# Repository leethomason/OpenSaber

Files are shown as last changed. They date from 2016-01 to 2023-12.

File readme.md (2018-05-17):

**Welcome to Open Saber**

The goal of open saber is provide source code, circuit diagrams, and 
documentation for making an Arduino (and compatible) based lightsaber.
The focus is on the internals of the saber, not how to build the case.

Why? For the joy of the problem, working together, and learning / playing
with Arduinos. There are certainly commercial solutions to saber electronics,
but if you want to build and contribute to the code and internals, this site
is for you!

The information and documentation assume a basic knowledge of Arduinos,
electronics, soldering, etc.

In 2017, the design switch from through hole components, which have wires
and can be fairly easily hand soldered, to SMD components, which need
to be flow soldered in an oven. The current code uses only the SMD
approach. If you are interested in the through hole approach, check out
the source at FIXME

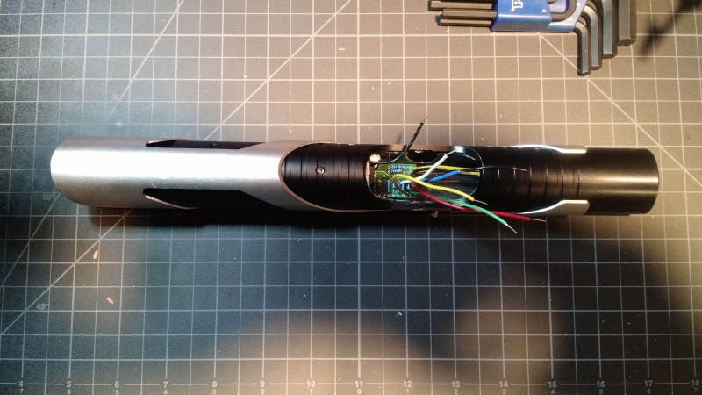
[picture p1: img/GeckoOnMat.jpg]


The Open Saber site / repo is 3 things:
- Overview of the (electrical) design of a saber.
- Source code for blade ignition, color, sound, etc. that runs on
  arduino class micro-controllers.
- Documentation & circuit diagrams for circuits and components.

An Open Saber electronics in action here: https://youtu.be/9_-Rfe4UBJM.

## Features:
- Support for 3 LED RGB "any color" saber 
- Flash on clash
- Motion and impact detection
- Sound font support
- Constant (average) current to LEDs
- Battery level tracking and indicator
- Command set to program saber with computer
- Recharge port / kill key port
- SPI support for secondary display, etc.
- Dotstar support for UI, etc.

## Status & Direction

There are over 5 working sabers on the OpenSaber design with cases
by SaberZ, UltraSabers, TCSS v1, and SaberForge ASP.

The version number - as much as it is consistent - references
the PCB board. The PCB board is called a "shield" because it sits on top
of a Teensy Microcontroller.

I use the largest possible SMD components to make it as straightforward
as possible for a human to solder. They are still *small*.

Generally speaking the shields sit on a Teensy 3.5. You can also use a
Teensy 3.2, but you need to connect an SD card on the SPI interface.
(The 3.2 does not have an integrated SD card.)

- Shield V3: Does *not* have integrated LED resistors. The emitter LED
  needs to have the correct resistors soldered in place.
- Shield V4: Has space for 3 through hole, small form factor, 1W 
  resistors. This can be much more tidy, but it's a longer board.

Note that many commits to the github repo are parts for a 3D
printer. While you are welcome to use them, the focus of 
this site is the electronics, which can be re-used from saber
to saber. The physical parts are unique to each saber (unless
you use a standard case, of course.)

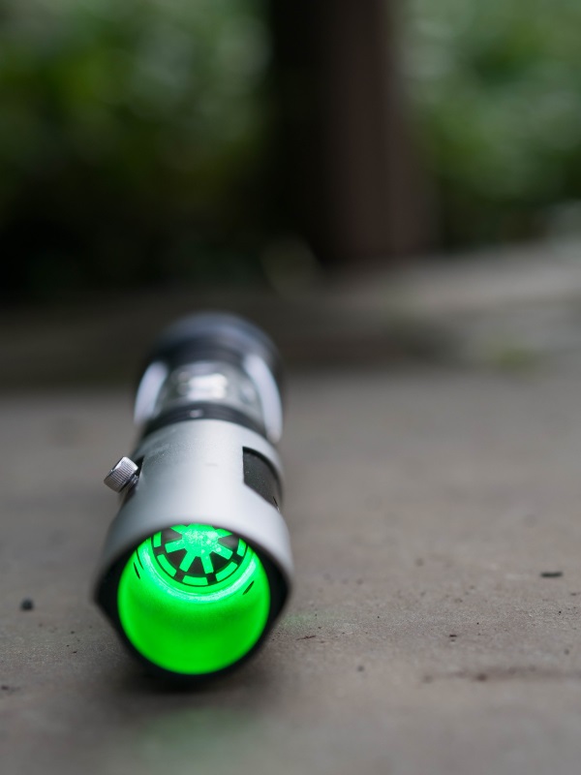
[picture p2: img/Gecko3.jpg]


## Alternate Approaches

- http://www.rocket-props.com/the-open-source-saber-project uses some 
  interesting ideas, including SMD componends and using buck-pucks.
  Nice approach, very different from this one.
- The Teensy Based Lightsaber http://fredrik.hubbe.net/lightsaber/
  has a similar electrical design, some innovative features, and
  doesn't use a PCB. (Which has pros and cons.)

## Resources

I am not affiliated with any of these, but have found them all useful.

### General
- The Custom Saber Shop at http://www.thecustomsabershop.com
  has all things saber. Often just abbreviated TCSS.

### How To
- Genesis Custom Sabers Shop Secrets: 
  https://www.youtube.com/playlist?list=PLBZx-DMVqx7druzwlBkXoZZhd30_0LXNS
  Lots of good info on wiring and techniques.
- "So you want to build a LED saber?" Different design than Open Saber,
  but still a nice overview: 
  http://forums.thecustomsabershop.com/showthread.php?2025-Step-2-I-have-decided-to-make-a-LED-saber

### Saber bodies
- The Custom Saber Shop (http://www.thecustomsabershop.com)
- UltraSabers http://www.ultrasabers.com/, in the "Build your own
  Lightsaber" section.

### LEDs
- LEDSupply. http://www.ledsupply.com/ has some nice RGB high power LEDs.

### Electronics
- Adafruit. I'm a huge Adafruit fan; great electronics and documentation.
  http://adafruit.com/
- PJRC who makes the Teensy and the Prop Shield.
  https://www.pjrc.com/
- Polulu makes some nice, simple breakout boards. https://www.pololu.com/
- Sparkfun. https://www.sparkfun.com/
- Mouser. http://www.mouser.com/ A huge selection of everything electronic.
- DigiKey. http://www.digikey.com/ A huge selection of everything electronic.
  I tend to have more success with DigiKey's search engine.
- Amazon has a surprisingly good selection of components.

## Architecture

An overview of the parts of a saber, with specific examples of the Gecko. 

Technically speaking, to organize you electrical thoughts, a saber is a *very* 
fancy flashlight. 

In roughly front to back order, an saber is:

1.  A **blade holder**. (1" is standard.)
2.  A **lens** to focus the LED. The lens is bought to match the LED,
    and narrower is usually better.
3.  3 **LEDs** in the 1-Watt each range. Red, green, blue, and 
    sometimes white or another color. I like both the Luxeon and Cree XPE-2.
    I haven't experimented with the 12W LEDs yet; electrically
    most of the designs should handle it, but the power from the battery
    and the cooling are potential issues.
4.  A **heat sink** for cooling the LED. Often part of the saber body. 
    TCSS provides them as well. LEDs are kept to 350ma - 400ma each (although 
    you can change this.) Many LED's, if cooled correctly, can take considerably
    more power. Conversly, many sabers with poor heat sinking fail over time
    as their LEDs burn out.
5.  **Power and Auxillary** switches (momentary on, typically 12mm). The
    code supports both a one button version and a two button version. Both
    versions support the same features except "clash sound" which is only
    supported in the 2 button version. If the switches have LED rings, the
    microcontroller will use them for power / volume display.
6.  **Electronics**. Please see the full discussion below.
7.  **Power port**. Typically 2.1 mm. If plugged into a Li-Ion charger,
    charges the battery (and disconnects the microcontroller). If a kill key
    is inserted, turns off the saber.
8.  **SD Card**. A simple SD card breakout board or integrated card. This is 
    where the sound fonts are stored. Note that the saber code WILL NOT work 
    without sound fonts stored and named properly on the MicroSD card. Also,
    if using the Teensy 3.5, the SD card is integrated.
9.  3.7v Li-Ion **battery**. TCSS and Adafruit both sell good, small,  long 
    lasting batteries. Need something rated 2000mAh or better. Amazon as well
    carries protected Li-Ion batteries. (The Panasonic NCR18650B 18650 has 
    been recommended.)
10. **Speaker**. TCSS and Adafruit carry them, as well as Mouser and Digikey. 
    (I've had a lot of inexpensive speakers arrived damaged from China, so I 
    do recommend a reputable supplier.)

## Directory Organization

- root
  - src - ardruino source code
    - saber - code for the saber itself
  - circuits
    - pcb - printed circurit board diagrams
  - img - images and diagrams used by the docs

## Wiring

FIXME new wiring diagram
  
### LEDs

LEDs are used in a bunch of places. Specific concerns are discussed
below, but for all the LEDs it's good to have a handly calculator.
The Vf comes from the LED data sheet. The Vsource depends on
which circuit it is connected to.

A LED calculator: http://led.linear1.org/1led.wiz

This calculator will select the next higher standard resistor,
which is almost always what you want. However, if you want to 
calculate the exact resistance:

R (ohms) = (Vs - Vf) / amps_through_led

Specific LED usage:

- The high power LED that lights the blade. Powered by the battery
  at 4.2 to 3.5 volts. Typcially about 1 Watt
  (or higher) per channel, and the resistors are typically 1 Watt.
  Typically a Vf of about 3.0 and expects 350mA of power. But
  get correct values from the datasheet! Generally has a resistor
  of 1-4 ohms. Note that once you select an LED, and add the
  resistor and specs into the `pins.h` file, the microcontroller
  will use PWM to keep the power at the specified level (or less.)
  This means you can sometimes round down on the resistor values:
  for example, if the `perfect` resistor is 1.6 ohms, and the 
  calculator recommends 1.8 ohms, you might use a 1.5ohm to give
  the microcontroller a little more "range" to work with.

- LED indicator lights, usually on the buttons. Powered at Vcc,
  3.3 volts, stable from the microcontroller. In theory these
  often take 20mA, about a 47 ohm resistors. But that is BRIGHT.
  I often use 470 or 1000 ohm resistors.

- DotStar smart LEDs. Used for user indicators. (Power meter,
  volume, etc.) Driven by the prop shield, requires no resistors.
  (The provided wiring diagram does not include this.)

### Power Bus

The saber uses a common ground. There are 4 positive power voltages. Please
be aware of the power supply. Shorts between the supplies can cause big
issues. It's very important to not "cross" the power supplies or use the 
wrong one. 

- Vbat, the battery power supply. Ranges from about 4.2 - 3.5V. Vbat delivers
  a **lot** of power, up to about 1A (1000mA) to the audio and LEDs. It also
  powers the micro-controllers.
- Vcc, a 3.3V, regulated, constant, low-amp supply. Powers the switch LEDs and 
  other indicators. Vcc is provided by the microcontroller.
- V5. If the propshield as well as Dotstar LEDs are being used, then there
  should be a 5 volt power supply. I often use a super-tiny booster 
  (from Polulu) to go from Vbat to V5 to power the microcontroller.
- USB. When the saber is plugged into USB, there is Yet Another power supply.
  WARNING: it is VERY easy to short a Teensy by plugging in a standard USB
  cable. This causes a short between the 5V USB power supply and the 3.7V
  Li-Ion battery. This will destroy the saber. Your options:
    - Cut the USB power on the Teensy board. I don't recommend this; it
      seems much too easy to "reconnect" via a short (metal dust?) or
      thermal expansion. I've burned out 3 microcrotrollers due to 
      mysterious issues when connecting USB.
    - Cut the power (red) line in the USB cable. Much more reliable...but
      you must *always* use the modified cable. I mark the USB port in 
      red paint and the cables with red tape.

#### Power Port
Convention, and the current design, uses a 2.1mm recharge jack. Wiring of the
jack is such that:
1. the battery charges when the charger is plugged in
2. the circuit is dead when there is a non-conductive kill key plugged in
3. the circuit is live when nothing is plugged in, which is also
   indicated by the ring LED if you use that type of momentary switch.

This is useful, and convention for almost all saber designs, but a little 
weird. For it to work (safely) for case #1, the grounded sleeve of the recharge 
port should be isolated from "true ground" and the case of the saber. You need 
to be careful with a metal port, or use an insulated plastic one.

#### 3V or 7V

Sabers run off 4 AAA, 3.7 Li-Ion, or 7.4 Li-Ion. OpenSaber is designed 
around a 3.7 Li-Ion.

Why?

3.7v
- Rechargable 
- Smaller than 7.4, competitive with AAA
- Efficient for resistors on LEDs. A typical LED forward voltage is 2-3 volts,
  so overall efficiency is about 80%.
- Buck/Boost converters make the 7.4 supply less interesting for the
  microcontroller and DotStars. 

Note that the actual battery voltage varies significantly, 
and the control circuit accounts for that.

### Electronics

The electronics are the heart of the OpenSaber project. The files are
ExpressPCB files. I regret the proprietary solution, but I've been happy
thusfar with the service.

The shield - which is the PCB that sits on top of the Teensy - collects 
together 1) an audio amplifier, 2) a DotStar LED controller,
3) an accelerometer, and 4) and emitter LED power onto one board. It also 
provides an SPI inteface connection for an external SD card, display, or 
similar.

- A **microcontroller**, the Teensy 3.2 or 3.5, is the micro-computer
  that runs the software. It controls the blade state, the color
  of the LEDs, the color of the blade, and does audio processing.

  It is soldered to a shield PCB. The microcontroller
  can be programmed directly via USB. The 3.5 includes an integrated
  SD card (handy!), but an SD breakout board can be connected via
  the SPI interface.

- **LED amplifier** The LED uses a 3 channel, 350ma (average) controller.
  The microcrontroller uses an amplifier bridge made of 3 MOSFETS
  to drive the LEDs. Voltage monitoring is used to keep the LED current
  constant. You may change the LED current in the software.

- **LED** a 1 WATT Cree or Luxeon LED in a star configuration is typical.
  The LED uses a common anode, as well as 3 control lines: Red, Green, and
  Blue. They 4 wires are connected from the LED to the front side of the 
  emitter electronics.

### Switches

The code assumes 1 or 2 switches.
- A: the main switch. Hold for power, tap for battery level indicator.
- B: the auxiliary switch. When the blade is on, tap for "blaster effect",
  hold for "lockup effect". When the blade is off, hold to toggle sound.
  When the sound turns on, hold for 1-4 flashes to set volume.

In a 2 switch configuration, you may also (when the blade is on) 
hold auxillary and then tap the main switch to cycle through the blade 
color / sound palettes.

In a 1 switch configuration, a tap mode switches between "blade", "palette",
and "volume". Long press either turns the blade on/off, or selects the 
palette or volume.

### Audio

Audio playback is integrated into the main micro controller. It takes
44.1kHz in; you will need to convert files to 44.1k. They are typically
*not* 44.1kHz when provided, so you will need to convert.
- http://www.foobar2000.org/
- http://www.huelix.com/audio-converter/

You can have up to 10 sound "fonts" or sound banks. Each font
needs to be in its own sub-directory, which will be the name of the font.

All the names can be postfixed with a number for random variation: `SWING` or
`SWING01` for example. Note that the card / code is limited to 8.3 filenames.
You can't mix names in a group; using both BLDON and POWERON in the same
sound font will confuse the sound output.

- "BLDON", "POWERON" blade ignition
- "BLDOFF", "POWEROFF" blade retraction
- "IDLE", "HUM" the background drone
- "IMPACT", "CLASH" is the sound of impacting another saber
- "MOTION", "SWING" is the basic saber motion sound
- "USRHOLD", "LOCKUP" is a user defined long sound, typically the sound 
  when 2 sabers are held together.
- "USRTAP", "BLASTER" is a user defined short sound, typically the sound
  of parrying blaster fire.

## Code

The code is really the heart of this project. The code
is set up to compile in the Arduino IDE, using the Teensyduino extension.

First you will need to set up libraries. Then you need to configure
you particular saber in "pins.h".

### Libraries

I feel guilty about every forked library; but it's hard to
work around API issues. Theser are minor forks, at least.

#### Accelerometer

The current design uses the (really great) LIS3DH.
https://github.com/leethomason/Adafruit_LIS3DH

#### OLED

The OLED display is required to compile, although it isn't supported
as part of OpenSaber yet. (I use it in a personal saber.)

https://github.com/leethomason/OLED_SSD1306

### Config Files

#### 'pins.h'

'pins.h' contains the wiring pinout, documentation, and features switches.
The tricky #define is the SERIAL_DEBUG macro. If on, you can connect
the USB header and debug the saber. However, without a USB connection, **the 
saber won't work if SERIAL_DEBUG = 1**. The serial port won't be found,
the timeouts kick in, and the saber essentially "locks up". It's a great to
be able to debug, but remember to SERIAL_DEBUG=0 and upload that sketch
when you are done.

Pins contains a bunch of other macros, which you can disable when you 
build the saber, and turn on one by one.

'pins.h' also contains the description of the LED: forward voltage, 
resistor values, etc. You need to set this for your particular build.

Note that there is an equation for UVOLT_MULT which controls the volt
meter. There's some variability; once the saber is assembled, I suggest
adjusting this value by checking computed vs. measured values. (Type 'vbat' on 
the command line to get the current computed value.)

##### "Constant Current" and tuning the voltmeter.

The OpenSaber code will maintain an average of 350mA current
(or whatever you specify) across the LED. This block of code in pins.h
is important for tuning:

````
  static const int32_t UVOLT_MULT = 6680;
  #define ID_STR "Gecko (Sentris Body) RGB Luxeon"

  static const int32_t RED_VF   = 2900;   // milli-volts
  static const int32_t RED_I    = 350;    // milli-amps
  static const int32_t RED_R    = 2400;   // milli-ohms
````

VF: forward voltage, from the LED spec.
I: milli-amps of power
R: the resistor value you used

And finally the UVOLT_MULT. It's a little tedious to calculate,
and doesn't turn out to be useful to do so. Once your saber 
is up and running, wait until it hits the 3.7 volt range.
Measure the power with a voltmeter. Run `vbat` on the saber
command line to get the measured value. Adjust UVOLT_MULT,
and recompile.

UVOLT_MULT' = UVOLT_MULT * V_measured / vbat

And then re-check the `vbat` just to be sure. It should 
be close, but doesn't need to be exact.

### Command line

If you connect via USB, you can open the COM port to the saber and
issue commands. Do this by opening the Serial Monitor and entering
comminds in the terminal that appears. This works irrespective of 
SERIAL_DEBUG.

The saber has 8 palettes. The palette is a combination of:
- blade color
- impact color
- sound font

- `bc` will return the current blade color for current palette. `bc #rrggbb`
  will set the blade color for the current palette. It will also show the 
  current draw of the color. I generally keep it at 1000mA or less, although
  you could theoretically draw about 1/2 the batter capacity. Do keep in mind
  how well your LED is able to sink heat.
- `ic` gets / sets the impact color or "blade flash".
- `pal` returns the current palette. `pal <0-7>` sets the current palette.
- `font` gets/sets the sound font in use.
- `fonts` lists the available sound fonts.
- `vol` and `vol <0-204>` gets and sets the current volume.
- `vbat' is the current battery level, in milli-volts. 4200 is fresh, 3700 is 
  nominal, 3500 is low. This is read from the Vmeter of the emitter circuit.
- `util` is the current utilization of each channel. It is computed from Vbat.
  `90 90 76` means that the saber will use 90% red, 90% green, and 76% of
  the blue channel. This keeps the average current through the LED constant.
  When Vbat drops to 3.7V, these will all be 100%.
- `pwm` is the current Pulse Width Modulation of the red, green, and blue LEDs.
- `mot` and `mot <1.1+>` gets and sets the threshold, in g-force, that
  the saber will detect as motion, and play the motion sound effects.
- `imp` and `imp <1.1+>` gets and sets the threshold, in g-force, that
  the saber will dectect as impact, and play the impact sound effects.
- `stat` will display all of the current saber settings.
- `reset` will reset the palettes to their default values.
- `accel` prints the current accelerometer output. Useful for checking
  calibration and that your axis are set up correctly.
- `test` runs the saber test suite.
- 'play' plays a sound on the SD card. You need the full name: 'play demichel.wav'
   or 'play bespin2/hum.wav'

## Future Direction

In practice I've found that there are two drivers to the design:
- Size. Smaller electronics leads to more features that can be packedd into
  theh saber. I try to balance size with ability to be soldered and
  wired up.
- Features for sabers. With every saber I build I put in some new or
  novel feature. (Although sometimes this is in the case, not electronics.)
  But those changes and improvements are reflected here

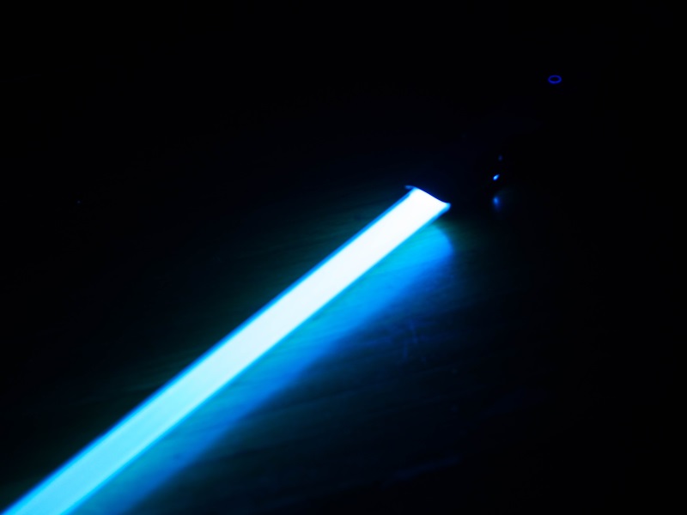
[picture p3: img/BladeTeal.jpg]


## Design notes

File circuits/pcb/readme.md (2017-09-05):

A collection of printed circuit boards used to make Open Saber designs.

`pcb` files are printed by ExpressPCB.

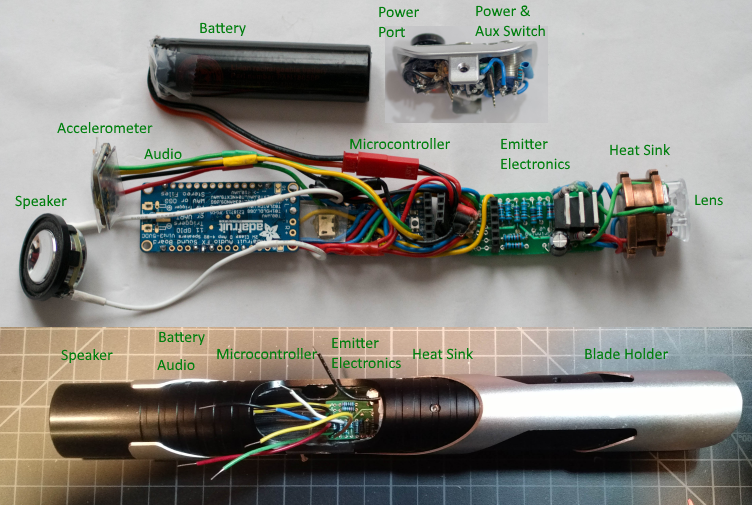
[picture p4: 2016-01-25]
img/Schematic.png

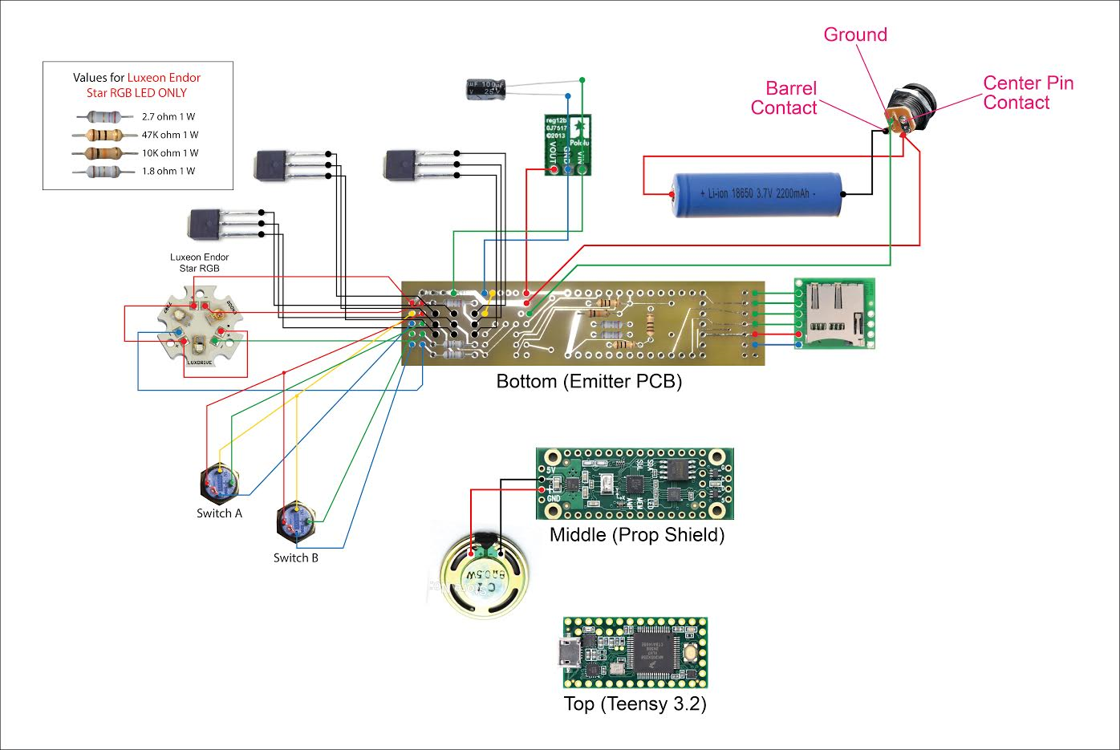
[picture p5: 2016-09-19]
img/v5prop.png

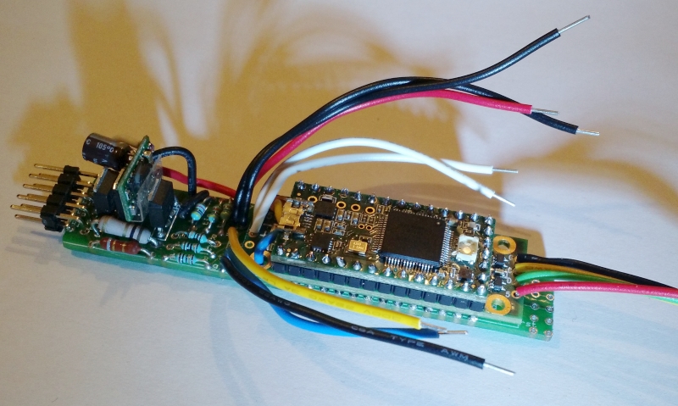
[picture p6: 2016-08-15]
img/v5propShield.jpg

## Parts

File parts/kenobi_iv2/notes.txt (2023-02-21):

* check mounting hardware works with 2mm mount
* set pin
* switch to rails to hold pcb

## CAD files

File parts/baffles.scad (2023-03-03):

use <shapes.scad>

D_OUTER = 2;
D_THIN  = 3;
D_INNER = 6;

module curveBridge(h, y, z, low, high)
{
    EPS = 0.1;

    // a + b*t + c*t*t + d*t*t*t
    al = low[0];
    bl = low[1];
    cl = low[2];
    dl = low[3];
    ah = high[0];
    bh = high[1];
    ch = high[2];
    dh = high[3];

    t = z;
    points = [
        [-EPS, al],
        [0.1, al + 0.1*bl + 0.1*0.1*cl + 0.1*0.1*0.1*dl],
        [0.2, al + 0.2*bl + 0.2*0.2*cl + 0.2*0.2*0.2*dl],
        [0.3, al + 0.3*bl + 0.3*0.3*cl + 0.3*0.3*0.3*dl],
        [0.4, al + 0.4*bl + 0.4*0.4*cl + 0.4*0.4*0.4*dl],
        [0.5, al + 0.5*bl + 0.5*0.5*cl + 0.5*0.5*0.5*dl],
        [0.6, al + 0.6*bl + 0.6*0.6*cl + 0.6*0.6*0.6*dl],
        [0.7, al + 0.7*bl + 0.7*0.7*cl + 0.7*0.7*0.7*dl],
        [0.8, al + 0.8*bl + 0.8*0.8*cl + 0.8*0.8*0.8*dl],
        [0.9, al + 0.9*bl + 0.9*0.9*cl + 0.9*0.9*0.9*dl],
        [1.0+EPS, al + 1.0*bl + 1.0*1.0*cl + 1.0*1.0*1.0*dl],
        [1.0+EPS, ah + 1.0*bh + 1.0*1.0*ch + 1.0*1.0*1.0*dh],
        [0.9, ah + 0.9*bh + 0.9*0.9*ch + 0.9*0.9*0.9*dh],
        [0.8, ah + 0.8*bh + 0.8*0.8*ch + 0.8*0.8*0.8*dh],
        [0.7, ah + 0.7*bh + 0.7*0.7*ch + 0.7*0.7*0.7*dh],
        [0.6, ah + 0.6*bh + 0.6*0.6*ch + 0.6*0.6*0.6*dh],
        [0.5, ah + 0.5*bh + 0.5*0.5*ch + 0.5*0.5*0.5*dh],
        [0.4, ah + 0.4*bh + 0.4*0.4*ch + 0.4*0.4*0.4*dh],
        [0.3, ah + 0.3*bh + 0.3*0.3*ch + 0.3*0.3*0.3*dh],
        [0.2, ah + 0.2*bh + 0.2*0.2*ch + 0.2*0.2*0.2*dh],
        [0.1, ah + 0.1*bh + 0.1*0.1*ch + 0.1*0.1*0.1*dh],
        [-EPS, ah]
    ];

    multmatrix(m = [ [0, 0, 1, 0],
                     [0, y, 0, 0],
                     [z, 0, 0, 0],
                     [0, 0, 0, 1]
                ])
    linear_extrude(height = h) {
        polygon(points=points);
    }  	
}

module bridge2(d, dz)
{
    SPACE_I = 6.0;
    SPACE_O = 1.0;

    difference() {
        intersection() 
        {
            tube(h=dz, do=d - SPACE_O, di=d - SPACE_I);
            union() {
                translate([-d, d*0.15, 0]) {
                    polygonYZ(d*2, [
                        [0,0], [dz*2, dz*2], [dz*3.5, dz*1.5], [dz*2.5, 0]
                    ]);
                }        
                translate([-d, -d*0.32, 0]) {
                    polygonYZ(d*2, [[0,0], [dz*2, dz*2], [dz*3, 0]]);
                }        
            }
        }
        BATTERY = 19.0; // padded
        translate([0, d/2 - BATTERY/2, 0])
            cylinder(h=d, d=BATTERY);
    }
}

module bridge4UpperWall(d, dz)
{
    intersection() 
    {
        cylinder(h=dz, d=d - 1.0);
        union() {
            translate([-d/2 - 1.0, d*0.08, 0]) {
                rotate([0, 0, -35]) {
                    polygonYZ(2.0, [
                        [0,0], 
                        [dz*3.0, dz*2], 
                        [dz*3.0, dz*1.5], 
                        [dz*3.0, 0]
                    ]);
                }
            }        
        }
    }
}

module bridge4(d, dz)
{
    intersection() 
    {
        tube(h=dz, do=d - D_OUTER, di=d - D_INNER);
        translate([-d, -d*0.32, 0]) {
            polygonYZ(d*2, [[0,0], [dz*2, dz*2], [dz*2, 0]]);
        }        
    }
    bridge4UpperWall(d, dz);
    mirror([-1, 0, 0]) bridge4UpperWall(d, dz);
}

module bridge5(d, dz)
{
    EPS = 0.1;
    D_BATTERY = 18.50 + 0.5;    // An 1850. Huh. 
    difference() {
        intersection() 
        {
            tube(h=dz, do=d - 2.0, di=d - 8.0);
            union() {
                translate([-d, -d*0.35, -EPS]) {
                    polygonYZ(d*2, [[0,0], [dz*2, dz*2], [dz*2, 0]]);
                }        
                translate([-d, 0, 0]) {
                    polygonYZ(d*2, [
                        [0,0], [dz, dz+EPS*2], 
                        [d*0.4, dz+EPS*2], [d*0.25, 0]
                    ]);
                }        
            }
        }
        translate([0, d/2 - D_BATTERY/2, 0])
            cylinder(d=D_BATTERY + 1.0, h = dz+EPS);
    }
}

module bridge3(d, dz)
{
    difference() {
        union() {
            intersection() 
            {
                tube(h=dz, do=d - D_OUTER, di=d - D_INNER);
                union() {
                    translate([-d, 0, 0]) {
                        curveBridge(d*2, dz, dz, 
                            [-2.5, 1.0, 1.0, 0.0], 
                            [-1.5, 0.5, 2.0, 0.0]);
                    }
                    translate([-d, 0, 0]) {
                        curveBridge(d*2, dz, dz, 
                            [ 0.0, 1.0, 1.0, 0.0], 
                            [ 1.5, 0.0, 1.5, 0.0]);
                    }
                }
            }
            color("silver") 
            intersection() 
            {
                tube(h=dz, do=d - D_THIN, di=d - D_INNER);
                translate([-d, 0, 0]) {
                    curveBridge(d*2, dz, dz, 
                        [ 2.5, -1.0, -1.5, 0.0], 
                        [ 3.0, -1.0, 0.5, 0.0]);
                }
            }
            color("silver")
            intersection() 
            {
                tube(h=dz, do=d - D_THIN, di=d - D_INNER);
                translate([-d, 0, 0]) {
                    curveBridge(d*2, dz, dz, 
                        [ -0.8, -1.0, -0.5, -0.2], 
                        [ -0.2, -1.0, -0.1, 0.0]);
                }
            }
        }
        BATTERY = 19.0; // padded
        translate([0, d/2 - BATTERY/2, 0])
            cylinder(h=d, d=BATTERY);
        X = 19.0; // padded
        translate([-X/2, -d/2, 0])
            cube(size=[X, d/2, dz]);
    }
}

translate([0, 0, 0]) tube(h=4, do=32, di=26);
translate([0, 0, 8]) tube(h=4, do=32, di=26);
translate([0, 0, 16]) tube(h=4, do=32, di=26);
translate([0, 0, 24]) tube(h=4, do=32, di=26);
translate([0, 0, 32]) tube(h=4, do=32, di=26);

translate([0, 0, 4]) bridge3(32, 4);
translate([0, 0, 12]) bridge3(32, 4);
translate([0, 0, 20]) bridge3(32, 4);
translate([0, 0, 28]) bridge3(32, 4);


/*
translate([0, 0, 0]) cube(size=[1, 30, 4]);
translate([0, 0, 8]) cube(size=[1, 30, 4]);
translate([-1, 4, 4]) 
    curveBridge(0.8, 4, 4, [0, 1.0, 0.3, 0.1], 
                           [1, 1.0, 0.3, 0.1]);
translate([-1, 16, 4]) 
    curveBridge(0.8, 4, 4, [0, 1.0, 0.3, 0.1], 
                           [1, 1.0, 0.3, 0.1]);                           

translate([0, 16, 4]) 
    curveBridge(0.8, 4, 4, [0, -1.0, 0.3, 0.1], 
                           [0.6, -1.0, 0.3, 0.1]);
*/

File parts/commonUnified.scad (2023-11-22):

use <shapes.scad>
use <baffles.scad>

Z_BATTERY_18650     = 65 + 4;
Z_BATTERY_18500     = 50 + 5;
D_BATTERY           = 18.50 + 0.5;    // An 1850. Huh. 

D_SWITCH            =  12.5;     // actually 12, by thread.
D_SWITCH_SUPPORT    =  16;
DY_SWITCH            =  -2;

D_PORT              =  7.9;
D_PORT_SUPPORT      =  12;
H_PORT              =  16;

INCHES_TO_MM        = 25.4;
X_MC                =   0.7 * INCHES_TO_MM;
Y_MC                =   9.0;
Z_MC                =   2.2 * INCHES_TO_MM + 0.1;
DY_MC               = -12.5;

X_CRYSTAL           =  11;
Y_CRYSTAL           =   8.5;
Z_CRYSTAL           =  30.0;

D_M2                = 1.7;

EPS = 0.01;
EPS2 = EPS * 2;

// Math ------------

function yAtX(x, r) = sqrt(r*r - x*x);

function isSmall(d) = d < 29.5;

// Utilities, shapes. ------------------------
module capsule(theta0, theta1, r=2, _mirror=false)
{
    hull() {
        rotate([-90, -0, theta0]) cylinder(h=20, r=r);
        rotate([-90, -0, theta1]) cylinder(h=20, r=r);
    }
    if (_mirror == true) hull() {
        rotate([-90, -0, 180 + theta0]) cylinder(h=20, r=r);
        rotate([-90, -0, 180 + theta1]) cylinder(h=20, r=r);
    }
}

module triCapsule(theta0, theta1, r=2, _mirror=false)
{
    theta0 = theta0 + 90;
    theta1 = theta1 + 90;

    hull() {
        rotate([0, 0, theta0]) 
            polygonYZ(100, [[0, -r], [-r, 0], [0, r]]);
        rotate([0, 0, theta1]) 
            polygonYZ(100, [[0, -r], [r, 0], [0, r]]);
    }
    if (_mirror == true) hull() {
        mirror([1,0,0]) rotate([0, -0, theta0]) 
            polygonYZ(100, [[0, -r], [-r, 0], [0, r]]);
        mirror([1,0,0]) rotate([0, -0, theta1]) 
            polygonYZ(100, [[0, -r], [r, 0], [0, r]]);
    }
}

module columnY(dx, dyFrom0, dz, diameter, baseDX=0, baseDZ=0)
{
    intersection() {
        translate([0, 0, -dz/2]) cylinder(h=dz, d=diameter);
        hull() {
            translate([-dx/2, -diameter/2, -dz/2]) {
                cube(size=[dx, diameter/2 + dyFrom0, dz]);
            }
            translate([-(dx + baseDX)/2, -diameter/2, -(dz + baseDZ)/2]) {
                cube(size=[dx + baseDX, 1, dz + baseDZ]);
            }
        }
    }
}

/*
    The green-sky version of the key joint was large, but
    secure. Problematic is that it clicked together on the y
    axis so it's hard to run the wires. The jJoint=true version
    is by far the more successful design.
*/
module keyJoint(dz, do, di, slot, angle=0)
{
    DZ = dz;
    YTRIM = slot ? 0.6 : 0.0;
    ZTRIM = slot ? 0.4 : 0.0;
    T = do - di;

    intersection() {
        if (slot) {
            tube(h=DZ+2, di=di, do=do+1);
        }
        else {
            OVERLAP = dz * 0.75;
            difference() {
                union() {
                    cylinder(h=dz-OVERLAP, d=do);
                    translate([0, 0, dz-OVERLAP]) cylinder(h=OVERLAP, d1=do, d2=do-(T*0.2));
                }
                translate([0, 0, -EPS]) cylinder(h=100, d=di);
            }
        }

        union() {
            rotate([0, 0, angle]) 
                tjoint(dz, do, di, YTRIM, ZTRIM, slot);
            mirror([-1, 0, 0 ]) rotate([0, 0, angle]) 
                tjoint(dz, do, di, YTRIM, ZTRIM, slot);
        }
    }
}

/* 
    A simple bridge at 45 degrees for
    unsupported printing. Made to hold
    switches, boards, etc. 
*/
module simpleBridge(diameter, dyToTop, yThickness, dz, addWidth=0, flatFill=false)
{
    L = 50;
    delta = yThickness * 1.2;

    // Writing this without the 'if' enclosing the PATH
    // declaration revealed all sorts of interesting
    // OpenScad bugs.
    //
    if (flatFill) {
        PATH = [
            [-L, dyToTop - yThickness - L],
            [0, dyToTop - yThickness],
            [L, dyToTop - yThickness - L],
            [L, dyToTop],
            [delta + addWidth, dyToTop],
            [-delta - addWidth, dyToTop],
            [-L, dyToTop]
        ];
        translate([0, 0, -dz/2]) {
            intersection() {
                cylinder(h=dz, d=diameter);
                polygonXY(dz, PATH);
            }
        }
    }
    else {
        PATH = [
            [-L, dyToTop - yThickness - L],
            [0, dyToTop - yThickness],
            [L, dyToTop - yThickness - L],
            [L, dyToTop - L],
            [delta + addWidth, dyToTop],
            [-delta - addWidth, dyToTop],
            [-L, dyToTop - L]
        ];
        translate([0, 0, -dz/2]) {
            intersection() {
                cylinder(h=dz, d=diameter);
                polygonXY(dz, PATH);
            }
        }
    }
}

module bridge(dx, dy, dz, inset=0)
{
    h1 = dx * 0.57;
    h2 = dx * 0.65; 
    pillar = dx * 0.20;
    
    PATH = [ 
        [-dx/2, dy], 
        [-dx/2 + h1, dy],
        [-dx/2, dy-h2]
    ];

    INSET = [
        [-dx/2 - EPS, dy - inset],
        [-dx/2 - EPS, dy + EPS],
        [-dx/2 + inset, dy + EPS]
    ];

    intersection() 
    {
        translate([-dx/2, 0, 0]) cube(size=[dx, dy, dz]);
        difference() {
            union() {
                polygonXY(dz, PATH);
                mirror([1,0,0]) polygonXY(dz, PATH);

                translate([-dx/2, 0, 0]) cube(size=[pillar, dy, dz]);
                mirror([1,0,0]) translate([-dx/2, 0, 0]) cube(size=[pillar, dy, dz]);
            }
            if (inset > 0) {
                translate([0, 0, -EPS]) {
                    polygonXY(dz + EPS2, INSET);
                    mirror([1,0,0]) polygonXY(dz + EPS2, INSET);
                }
            }
        }
    }
}

// Physical components. ----------------------

function zBattery(type) = (type == "18500") ? Z_BATTERY_18500 : Z_BATTERY_18650;

module battery(outer, type) {
    dz = zBattery(type);
    color("yellow") translate([0, outer/2 - D_BATTERY/2, 0]) {
        cylinder(d=D_BATTERY, h = dz + EPS2);
    }
}

function dynamicHeatSinkThread() = 20.2;  // 20.4 is loose (PHA), 20.1 tight (PLA)

module dynamicHeatSinkHolder(diameter)
{
    DZ = 10;
    D_HEAT_SINK_THREAD = dynamicHeatSinkThread();

    difference() {
        cylinder(h=DZ, d=diameter);
        translate([0, 0, -EPS]) 
            cylinder(
                h=DZ + EPS*2, 
                d1=D_HEAT_SINK_THREAD + 0.2, 
                d2=D_HEAT_SINK_THREAD + 0.4
            );
    }
}

module shortDynamicHeatSinkHolder(diameter)
{
    DZ = 4.0;
    D_HEAT_SINK_THREAD = dynamicHeatSinkThread();

    difference() {
        cylinder(h=DZ, d=diameter);
        cylinder(h=DZ + EPS, d=D_HEAT_SINK_THREAD);
    }
}


DOTSTAR_XZ = 5.6;
DOTSTAR_PITCH = 7;
DOTSTAR_STRIP_XZ = 12.4;

module dotstarLED(n, dy, pitch=DOTSTAR_PITCH)
{
    for(i=[0:n-1]) {
        translate([-DOTSTAR_XZ/2, 0, pitch * i - DOTSTAR_XZ/2]) {
            cube(size=[DOTSTAR_XZ, dy, DOTSTAR_XZ]);
        }
    }
}

function dotstarStripZLen(n, pitch=DOTSTAR_PITCH) = DOTSTAR_STRIP_XZ + pitch * (n-1);

module dotstarStrip(n, y0=0, y1=1, pitch=DOTSTAR_PITCH)
{
    translate([-DOTSTAR_STRIP_XZ/2, y0, -DOTSTAR_STRIP_XZ/2]) {
        cube(size=[ DOTSTAR_STRIP_XZ, 
                    y1 - y0,
                    dotstarStripZLen(n, pitch)]);
    }
}


module switch(outer, extend=false)
{
    D_OUTER_TOP = 13.8;
    D_INNER_TOP = 11.0;
    H_TOP       =  1.5;
    H_BODY      = 18;   // approx. connections below.

    color("yellow") {
        rotate([-90, 0, 0]) {
            translate([0, 0, outer/2 + DY_SWITCH]) {
                if (extend) {
                    cylinder(h=H_TOP+10, d=D_OUTER_TOP+1);
                }
                else {
                    cylinder(h=H_TOP, d1=D_OUTER_TOP+1, d2=D_INNER_TOP);
                }
                translate([0, 0, -H_BODY]) {
                    cylinder(h = H_BODY + EPS, d=D_SWITCH);
                }            
            }
        }
    }
}


module switchCounter()
{
    color("yellow") {
        rotate([90, 0, 0]) {
            cylinder(h=30, d=12);
        }
    }
}


module mc(widePart=0)
{
    color("aqua") {
        translate([-X_MC/2, 0, 0])
            cube(size=[X_MC, Y_MC, Z_MC]);
    
        Y_OFFSET = 4;
        if (widePart > 0) {
            translate([-widePart/2, Y_OFFSET, 0])
                cube(size=[widePart, Y_MC - Y_OFFSET, Z_MC]);
        }
    }
}

module crystal(dx=X_CRYSTAL, dy=Y_CRYSTAL, dz=Z_CRYSTAL)
{
    TAPER = 5;
    color("pink") scale([1.0, dy/dx, 1.0]) {
        cylinder(d=dx, h=dz - TAPER);
        translate([0, 0, dz - TAPER])
            cylinder(h=TAPER, d1 = dx, d2=dx *0.7);
    }
}

module port(extend=false)
{
    H = extend ? 30 : 21;
    rotate([-90, 0, 0]) {
        cylinder(h=H, d=D_PORT);
    }
}

module portCounter()
{
    H = 30;
    rotate([90, 0, 0]) {
        cylinder(h=H, d=12);
    }
}

module speakerStd28(bass)
{
    H_SPKR        =  3.5;
    D_SPKR        =  28;
    X_NOTCH       =  6;
    Z_NOTCH       =  6.0;

    color("yellow") {
        cylinder(h=H_SPKR, d=D_SPKR);
        translate([-X_NOTCH/2, 0, 0])
            cube(size=[X_NOTCH, D_SPKR * 0.6, Z_NOTCH]);
    }
}
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

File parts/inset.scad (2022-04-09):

use <shapes.scad>
use <commonUnified.scad>

SWITCH_BRIDGE_DZ = 5.8;
INNER_VIEW = false;

WOOD_DY = -8;
POWER_DY = 2.5;
EPS = 0.01;
EPS2 = EPS*2;

module attachPost(diameter, postDY, capsuleWidth)
{
    BRIDGE_DY = 5.5 + 3.4;
    BRIDGE_DZ = 10;

    BOLT_D = 4.5;
    NUT_W = 8.6;
    NUT_Y = 3.4;
    
    HOOK_X = 20;
    HOOK_Z = 2;

    INSET_DZ = 2;

    Y_TOP = diameter / 2 - postDY;

    intersection() {
        intersection() {
            translate([0, 0, -50]) cylinder(h=100, d=diameter);
            // This is a little limit to clean up the design.
            DELTA = 1.5;
            translate([-diameter/2 + DELTA, -100, -50])
                cube(size=[diameter - DELTA*2, 200, 200]);
        }
        union() {
            // bridge
            difference() {
                translate([-50, Y_TOP - BRIDGE_DY, -BRIDGE_DZ/2]) {
                    cube(size=[100, BRIDGE_DY, BRIDGE_DZ]);
                }
                // space for nut
                translate([-NUT_W/2, Y_TOP - BRIDGE_DY - EPS, -BRIDGE_DZ/2 - EPS]) {
                    cube(size=[NUT_W, NUT_Y + EPS, BRIDGE_DZ + EPS2]);
                }
                // bolt
                rotate([-90, 0, 0])
                    cylinder(h=20, d=BOLT_D);

                translate([-capsuleWidth/2, 0, -INSET_DZ/2])
                    cube(size=[capsuleWidth, 100, INSET_DZ]);
            }

            Y_HOLDER = Y_TOP - BRIDGE_DY;
            MULT = 0.3;
            translate([0, 0, -INSET_DZ/2]) {
                polygonXY(h=INSET_DZ, points=[
                    [-50,  Y_HOLDER],
                    [-NUT_W * MULT, Y_HOLDER],
                    [-50, -50]
                ]);
                mirror([-1,0,0]) polygonXY(h=INSET_DZ, points=[
                    [-50,  Y_HOLDER],
                    [-NUT_W * MULT, Y_HOLDER],
                    [-50, -50]
                ]);
            }
        }
    }
}

module insetBaffle(diameter, dzBaffle, bridge, noBottom=false)
{
    difference() {
        oneBaffle(diameter, dzBaffle, 
            bridge=bridge, 
            battery=false, 
            mc=true, 
            conduit=true, 
            noBottom=noBottom);

        hull() {
            cylinder(h=dzBaffle*1.1, d=diameter * 0.65);
            translate([0, -2.5, 0])
                cylinder(h=dzBaffle*1.1, d=diameter * 0.7);
        }
        
    }
}


// Origin top, center, back of pins.
module headerHolder(diameter, dy)
{
    HEADER_HOLDER_T = 2.0;
    HEADER_HOLDER_DZ = 2.6;
    DX = 10;
    D_OPEN = 6.3;

    //intersection()
    {
        //translate([0, 0, -20]) cylinder(h=300, d=diameter);
        translate([0, dy, 0])
            difference() {
                translate([-(DX/2 + HEADER_HOLDER_T), -20, -(HEADER_HOLDER_DZ + HEADER_HOLDER_T)]) {
                    cube(size=[DX + 2*HEADER_HOLDER_T, 20, HEADER_HOLDER_DZ + 2*HEADER_HOLDER_T]);
                }
                translate([-DX/2, -20, -HEADER_HOLDER_DZ])
                    cube(size=[DX, 21, HEADER_HOLDER_DZ]);
                translate([-D_OPEN/2, -20, -HEADER_HOLDER_DZ-HEADER_HOLDER_T-1])
                    cube(size=[D_OPEN, 21, HEADER_HOLDER_DZ+HEADER_HOLDER_T+1]);
        }
    }
}

module switchHolder(diameter, dzSwitch, dyInset, dySwitch, bridged)
{
    echo(diameter, dzSwitch, dyInset, dySwitch);

    rInner = diameter / 2;
    X_SWITCH = 6.5;
    Y_SWITCH = 3.0;
    Y_BASE = rInner - dySwitch - dyInset;

    intersection() {
        BRIDGE_T = 3;
        cylinder(h=300, d=diameter);
        translate([0, 0, dzSwitch - SWITCH_BRIDGE_DZ/2]) {
            if (bridged) {
                difference() {
                    translate([-20, Y_BASE - 20, 0]) cube(size=[40, 20, SWITCH_BRIDGE_DZ]);
                    translate([0, Y_BASE - 1, -EPS]) polygonXY(h=SWITCH_BRIDGE_DZ + EPS*2, points=[
                        [-20, -20], [0, 0], [20, -20]
                    ]);
                }
            }
            else {
                translate([-20, Y_BASE - BRIDGE_T, 0]) {
                    cube(size=[40, BRIDGE_T, SWITCH_BRIDGE_DZ]);
                }
            }

            translate([X_SWITCH/2, Y_BASE, 0]) {
                cube(size=[50, Y_SWITCH, SWITCH_BRIDGE_DZ]);
            }

            mirror([-1, 0, 0]) translate([X_SWITCH/2, Y_BASE, 0]) {
                cube(size=[50, Y_SWITCH, SWITCH_BRIDGE_DZ]);
            }
        }
    }
}


/*
    Creates a section with an inset holder, intended to give access to the switch
    and power, as well as lock the other case to the inner carriage.
*/
module insetHolder( diameter,
                    outerDiameter,
                    diameterCapsule,
                    dzSection,
                    dzBaffle,
                    dzStart,
                    dzEnd,
                    dzBolt = 0,
                    dzPort = 0,
                    dzSwitch = 0,
                    dzUSB = 0,
                    bridgeStyle=1,
                    bridgeStyleArray=undef,
                    firstButtressFullRing=true,
                    roundRect=0,
                    dzFore=0,      // make the first baffle this thicknes  (0 to use standard)
                    dyInset=5,
                    dySwitch=5.5,
                    flushPort=true,
                    frontBridge=true)
{
    rCapsule = diameterCapsule / 2;
    rInner = diameter / 2;
    yInset = rInner - dyInset;
    dzMid = (dzStart + dzEnd) / 2;
    dzCap = dzEnd - dzStart - diameterCapsule;
    dzA = dzStart + rCapsule;
    dzB = dzEnd - rCapsule;

    // check alignment
    // color("red") cylinder(d=10, h=dzSection);

    // Bridges
    X_SWITCH = 6.5;
    Y_SWITCH = 3.0;

    X_USB_OUTER = 25.0;     // Size of the outer holder. Bigger than USB PCB.
    X_USB_INNER = 13.0;     // Space inside for wires and plug
    Z_USB_OUTER = 6;        // Outer holder size
    USB_SLOT = 1.8;         // PCB cutout space
    X_USB_SLOT = 21.0;      // Width of PCB
    DEPTH_USB_SLOT = 11.0;   // Height of PCB

    difference() {
        union() {
            if (dzBolt)
                translate([0, 0, dzBolt])
                    attachPost(diameter, dyInset, rCapsule*2-4);

            // Switch flat version + header mount
            if (dzSwitch) {
                intersection() {
                    BRIDGE_T = 3;
                    cylinder(h=300, d=diameter);
                    translate([0, 0, dzSwitch - SWITCH_BRIDGE_DZ/2]) {
                        translate([-20, rInner - dySwitch - dyInset - BRIDGE_T]) {
                            cube(size=[40, BRIDGE_T, SWITCH_BRIDGE_DZ]);
                        }

                        translate([X_SWITCH/2, rInner - dySwitch - dyInset, 0]) {
                            cube(size=[50, Y_SWITCH, SWITCH_BRIDGE_DZ]);
                        }

                        mirror([-1, 0, 0]) translate([X_SWITCH/2, rInner - dySwitch - dyInset, 0]) {
                            cube(size=[50, Y_SWITCH, SWITCH_BRIDGE_DZ]);
                        }
                    }
                }
            }

            // Power holder.
            if (dzPort) {
                if (flushPort) {
                    T = 5.0;
                    L = 11.0;
                    difference() {
                        translate([-diameterCapsule/2, rInner - dyInset - T, dzPort - L/2])
                            cube(size=[diameterCapsule, T, L]);
                        translate([0, 0, dzPort]) rotate([-90, 0, 0]) cylinder(h=100, d=7.9);
                    }
                }
                else {
                    translate([0, 0, dzPort]) {
                        BRIDGE_T = 3;
                        intersection() {
                            translate([0, 0, -7 - 0.5])
                                cylinder(h=14 + 1, d=diameter - 1);
                            translate([-20, rInner - POWER_DY - dyInset - BRIDGE_T, -7])
                                cube(size=[40, BRIDGE_T, 14]);
                        }
                    }
                }
            }

            // USB holder
            if(dzUSB) {
                intersection() {
                    cylinder(h=300, d=diameter);
                    difference() {
                        translate([-X_USB_OUTER/2, yInset - 100, dzUSB - Z_USB_OUTER/2])
                            cube(size=[X_USB_OUTER, 100-EPS, Z_USB_OUTER]);
                        translate([-X_USB_INNER/2, yInset - 100, dzUSB - Z_USB_OUTER/2 - EPS])
                            cube(size=[X_USB_INNER, 100, Z_USB_OUTER + EPS*2]);
                    }
                }
            }
        }
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

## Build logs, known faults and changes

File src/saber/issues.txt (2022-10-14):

Issues:

Current
- implement general analogWrite (grumble)
- fix LED manager to be not weird, and not call arduino library funcs
- correct colors for darksaber
- sync wav12 to i2saudio2, test
- sync i2saudio2 to saber, test
- load new colors & sounds
- DARKSABER!
- Smooth out gyro sound?
x Retract is WAY too slow

High
- fix vol>255 not working
- volume boost support for fonts
- blade flash on retract. completely mystified

Med

Icebox

Notes
50  708080 (cool white)
40  596666
30  434C4C -> 414cc4
20  2D3333 -> 253333
10  161919 -> 101919

30 -> 65/67 -> 0.97
20 -> 37/45 -> 0.82
10 -> 16/22 -> 0.73

Fixed
x Turn off UI LED idle animation when there is a crystal
x Remove axis rotation from gyro
x switch to gyro.
x a little less motion sensitivity
x dropout during green spin
x fix floating point average to not drift
x clean up code
x tune swing intensity
x test button up on color wheel
x white is causing trouble
x set max swing (so it isn't over accumulating)
x sensitivity up and down
x test out filtering mag but not speed vectors - may not need decay code
x less motion sensitivity
x clipping / limiting in mixer (maybe 64 bit okay??)
x Crackle in hum sound (how??)
x correct sound font for leia
x smooth swing decay, decay class
x ignite / retract mode state
x playing hum past retract
x need to keep updating / reset magnemometer
x powerLevel or vbatToPowerLevel...both is crazy
x volume smoothing (driver)
x volume "drag" (SFX)
x Color section mode
x Tester: turn back on blade flash using delays
x Tester: Blade doesn't change color
x Fix analogReference(), deprecated by i2s audio
x blade flash on retract. Neopixel not the issue. Add assert?
    x range checks in fixed
    x start / end checks on interp
x high res mode for crystal / color.
  x fixed point computation
  x PWM for dotstar
x can reduce sub-buffer size? effect on perf? encapselation?
x drop vbat sample time, increase samples. move timing const into AveragePower class
x neopixels create noise: not fixed, but confirmed. neopixels throw off timers? But create noise. Dotstar does not.
x access to general pins
x power accelerometer
x clean up amp pins
x re-do ratline
x space out vias on board better
x trigger interupt from DMA? Remove timer?
x correctly connect amp select pin. Luck on my side, should be correctly setting left channel.
x enable shutdown pin on amp? 2-3mA draw. Basically an LED.
x dotstar support in itsy
x sound stutter
x experiment w/ different timing & buffers
x SPI is "over mutexed". there are 2 SPIs
x Better audio compression
x compact resistors
x extra capacitor for neopixels
x configure defaults correctly
x Support neopixel output
x fix / test accelerometer
x test on battery
x Fix voltmeter
x Sound based UI ("palette", "audio", "ready", 0-7)
x Connect RF24
x switch to new version
x PWM for LED
x select pin move/test (CSN is select)
x enable pin move/test (why are the names so bad???)
x initial role pin?
x start system with audio shutdown
x doesn't start with correct font
x test full circuit
x check alt grnd, vcc, etc. on battery circuit
x switch to battery version
x test audio output with scope
x test LED output with scope
x multiple sound banks
x font name
x fix sound light
x bootup sound
x shutdown audio
x ignite / retract times
x tune motion and impact
x read startup time from sound card
x red led for low power: flash power button?
x reset command
x optimize string uses, mem usage, etc.
x account for Vcc
x de-ring resistors
x rework MMA code
x figure out names: palette & font
x pull down resistors for gates. woh.
x sound on/off
x integrate sound calls into state code
x split out blade rendering code
x switch blade color banks
x correct ignite / retract times. From sound files?
x sound
x sound priorities
x motion sensing
x EEPROM writer sketch
x way to reset EEPROM

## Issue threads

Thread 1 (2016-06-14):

v3 Gecko: audible click / pop on startup

leethomason, 2016-06-14:
The amp shutdown doesn't get set in time?

leethomason, 2016-07-11:
Not on the "black" (Prop Shield) design. Going to live with this on the separate audio amp design.

Closed 2016-07-11.

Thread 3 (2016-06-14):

Accelerometer calibration

leethomason, 2016-06-14:
Basic build-in calibration and axis detection.

leethomason, 2018-01-23:
Not required for the simple use case (impact / motion) that is implemented now.

Closed 2018-01-23.

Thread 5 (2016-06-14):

Blade jitter

leethomason, 2016-06-14:
Constant jitter is a little obnoxious. But occasional jitter adds character. (At least as an option.) Should be part of configuration.

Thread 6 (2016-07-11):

Dotstar UI: power lights should use blade color palette

leethomason, 2016-07-11:
The red/green looks weird against a cyan or orange or purple blade. Would be nice to choose "red-ish" or "green-ish" in matching colors.

leethomason, 2018-01-23:
Fixed long ago.

Closed 2018-01-23.

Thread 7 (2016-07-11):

V3 dotstar UI too bright

leethomason, 2016-07-11:
Bring it down to the LED brightness?

leethomason, 2016-08-07:
It can be brought down to about 4-6 before it looses color resolution. 8 is probably better. But even at 4-8 it is a little on the bright side, compared to the lights on the AV switches. Although tricks could be done with color rounding, using a diffuser is probably the best approach. I may re-open this if the black knight is still too bright.

Closed 2016-08-07.

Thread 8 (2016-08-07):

Update docs for v3 design!

leethomason, 2016-08-07:
Uses the v5 PCB. (The versioning system could be better.)

hybridtheorist, 2016-08-11:
Hi Lee,
I've run into the 1st question: do you recommend using a DC Input Constant Current LED Driver with the Luxeon Rebel RGB LED? Or is the driver's function already covered by the V5 emitter PCB? Thank you so much.

All my best,
Bo

leethomason, 2016-08-11:
The V5 circuit uses resistors, not drivers. (Efficiency wise, it's about 80%, compared to a buck-puck with is about 90%. Both pretty good.) The microcontroller monitors the voltage, and adjusts the pulse frequency so that the *average* current to the LED is 350mA. This keeps the LED from over-heating and keeps the efficiency very high for a resistor approach.

Side note: when I last looked at LED drivers, they had 2 problems: 1) a little too big, and 2) drivers that had a dimmer / control line required 7V. Both were pretty big issues, but I haven't looked at the current gen of driver.

Another side note: Jacob over at Open Source Saber uses drivers if you want to see that approach: http://www.rocket-props.com/the-open-source-saber-project

leethomason, 2016-08-12:
@hybridtheorist Docs are updated for the current design. Please feel free to file issues on the docs as they come up.

Closed 2016-08-12.

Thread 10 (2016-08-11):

Need wiring diagram

leethomason, 2016-08-11:
"Thanks for the reply. It would be tremendous if you could sketch up a
similar wiring diagram to this one:
http://saberigniter.com/images/Spark2TriCreeBBR.png"

leethomason, 2016-08-12:
This has been added; check out "Wiring diagram" in the readme.md. It's only for the Prop Shield version currently, but if you are using the non-shield version, I'm happy to add that. Closing for now.

Closed 2016-08-12.

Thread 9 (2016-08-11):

Add section on voltmeter turning

leethomason, 2016-08-11:

leethomason, 2016-08-12:
Fixed.

Closed 2016-08-12.

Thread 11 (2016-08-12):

PJRC prop shield

hybridtheorist, 2016-08-12:
Hi Lee, please clarify the type of PJRC prop shield you recommend. Is it the low cost one without motion sensor (since the BOM already includes a triple-axis accelerometer):  http://www.pjrc.com/store/prop_shield_lowcost.html, or is it the more expensive version which include the motion sensor: http://www.pjrc.com/store/prop_shield.html? Thanks.

leethomason, 2016-08-12:
The Prop Shield version of the PCB does not have the accelerometer as a breakout board, so it uses the "full" prop shield: http://www.pjrc.com/store/prop_shield.html. (And under-uses it, honestly. The code is currently just using the accelerometer, not the gyroscope and other fancy functions.)

leethomason, 2018-01-23:
Closing - have since stopped using the prop shield. (Although it was super handy. But removing saved a lot of space.)

Closed 2018-01-23.

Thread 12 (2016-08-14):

Wiring diagram

hybridtheorist, 2016-08-14:
Thanks for adding the wiring diagram to readme.md, I will clean up your drawing and send you a nice one. Could you please also show how to connect the speaker and DotStar to the prop shield?  I will create the clean design based on your drawing as well and send the drawing back to you. - Bo

leethomason, 2016-08-15:
@hybridtheorist Thanks! A cleaned up version would be great. The Prop Shield wiring I didn't include, just because it's so literal.  Check out: http://www.pjrc.com/store/propshield_pinout.png. On the left, the speaker wires connect to Speaker+ and Speaker-. On the right, G-C-D-5 are the 4 standard lines for a DotStar LED. It wires straight up. (The DotStars are used for UI: power meter, volume meter, etc. as well as an internal crystal. They are completely optional, and not to be confused with the blade LED.)

Closed 2018-01-23.

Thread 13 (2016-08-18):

Regarding capcitors and MOSFETs

hybridtheorist, 2016-08-18:
I'm using a Luxeon Rebel Endor Star RGB High Power LED: http://www.ledsupply.com/leds/luxeon-rebel-endor-star-rgb-high-power-led. Based on a Vbat of 3.7V, 350 mA LED current and max LED Vf of 3.5V and 2.8V, the resistors I should use are 1 ohm 1/4 W and 2.7 ohm 1 W respectively.
Could you please clarify what type of capacitors (how many uF?) and MOSFET (IRF3205? IRF9530? Or it doesn't really matter?) you recommend for your current setup? Thank you!

leethomason, 2016-08-19:
I went with typical Vf on the Luxeon, and got similar results:
````
Luxeon Rebel Endor (Tri-LED)
Standard Resistors
R 2.90 @ 350 75% [2.7 ohm]
G 3.15 @ 350 83% [1.8 ohm]
B 3.15 @ 350 83% [1.8 ohm]
```
The capacitor is recommended near the power boost / LED, but I've never measured anything on an oscilloscope. I'm using 47uF - a couple hundred uF is probable better, but they are big and need to fit.

Any logic level mosfet that can handle 1W will work.
Adafruit / Digikey has an amazing one:
https://www.adafruit.com/product/355

And my favorite of a smaller package:
https://www.digikey.com/product-detail/en/infineon-technologies/IRLU024NPBF/IRLU024NPBF-ND/812400

But digikey has thousands of choices.

Closed 2018-01-23.

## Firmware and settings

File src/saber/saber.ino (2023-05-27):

/*
  Copyright (c) Lee Thomason, Grinning Lizard Software

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
  THE SOFTWARE IS PROVIDED "AS IS", WITHOUT WARRANTY OF ANY KIND, EXPRESS OR
  IMPLIED, INCLUDING BUT NOT LIMITED TO THE WARRANTIES OF MERCHANTABILITY,
  FITNESS FOR A PARTICULAR PURPOSE AND NONINFRINGEMENT. IN NO EVENT SHALL THE
  AUTHORS OR COPYRIGHT HOLDERS BE LIABLE FOR ANY CLAIM, DAMAGES OR OTHER
  LIABILITY, WHETHER IN AN ACTION OF CONTRACT, TORT OR OTHERWISE, ARISING FROM,
  OUT OF OR IN CONNECTION WITH THE SOFTWARE OR THE USE OR OTHER DEALINGS IN THE
  SOFTWARE.
*/

// #define PROFILE

// Arduino Libraries
#include <Adafruit_ZeroI2S.h>

#include "src/nada_flashmem/Nada_SPIFLash.h"
#include "src/nada_flashmem/Nada_FlashTransport_SPI.h"

#include "src/util/Grinliz_Arduino_Util.h"
#include "src/util/pwmwrite.h"
#include "src/lsm303/grinliz_LSM303.h"
#include "src/lsm6d/grinliz_lsm6d.h"

#include <Wire.h>
#include <SPI.h>

#include "OLED_SSD1306.h"
#include "Button.h"

// Includes
// -- Must be first. Has configuration. -- //
#include "pins.h"

#include "DotStar.h"
#include "voltmeter.h"
#include "sfx.h"
#include "saberdb.h"
#include "cmdparser.h"
#include "bladePWM.h"
#include "sketcher.h"
#include "uiDotStar.h"
#include "uiPixel75.h"
#include "renderer.h"
#include "saberUtil.h"
#include "tester.h"
#include "ShiftedSevenSeg.h"
#include "vrender.h"
#include "vectorui.h"
#include "bladecolor.h"
#include "swing.h"
#include "bladestate.h"

#include "src/i2saudio2/i2saudiodrv.h"
#include "src/wav12util/manifest.h"

using namespace osbr;

static const uint32_t INDICATOR_CYCLE         = 1000;
static const uint32_t IMPACT_MIN_TIME         =  600;   // was 1000

Nada_FlashTransport_SPI flashTransport(SS1, &SPI1);
Nada_SPIFlash spiFlash(&flashTransport);
Adafruit_ZeroDMA dma;

Manifest manifest;
Adafruit_ZeroI2S i2s(PIN_I2S_LRCLK, PIN_I2S_BITCLK, PIN_I2S_DATA, 2);
I2SAudioDriver i2sAudioDriver(&dma, &i2s, &spiFlash, manifest);
SFX sfx(&i2sAudioDriver, manifest);

ButtonCB    buttonA(PIN_SWITCH_A, Button::INTERNAL_PULLUP);
LEDManager  ledA(PIN_LED_A, false);
AnimateProp ledProp;

constexpr bool lockSupported = SABER_LOCK() ? true : false;
BladeStateManager  bladeStateManager;
UIModeUtil  uiMode(lockSupported);
SaberDB     saberDB;
Voltmeter   voltmeter(1650, 10000, 47000, 4095, VOLTMETER_TUNE);
BladeColor  bladeColor;
CMDParser   cmdParser(saberDB, bladeColor, manifest);
BladePWM    bladePWM;
Tester      tester;
bool        lockOn = false;
LockTimer   lockTimer;

#if SABER_ACCELEROMETER == SABER_ACCELEROMETER_LSM303
Swing       swing;
MagFilter   magFilter;
#endif

#ifdef SABER_NUM_LEDS
DotStar dotstar;                    // Hardware controller.
#endif
#ifdef SABER_UI_START
DotStarUI dotstarUI(lockSupported);                // It is the DotStarUI regardless of physical pixel protocol
#endif
#if ITSY_DOTSTAR_UI()
DotStar oneDotstar;
DotStarUI oneDotstarUI(lockSupported);
#endif

ACCELEROMETER accelMag(PIN_ACCEL_EN);

#if SABER_DISPLAY == SABER_DISPLAY_128_32
static const int OLED_WIDTH = 128;
static const int OLED_WIDTH_SHIFT = 7;
static const int OLED_HEIGHT = 32;
uint8_t oledBuffer[OLED_WIDTH * OLED_HEIGHT / 8] = {0};

OLED_SSD1306 display(PIN_OLED_DC, PIN_OLED_RESET, PIN_OLED_CS);
VRender    vRender;
Renderer   renderer;
VectorUI   vectorUI;

int renderStage = 0;
#elif SABER_DISPLAY == SABER_DISPLAY_7_5
Pixel_7_5_UI display75;
ShiftedDotMatrix dotMatrix;
#define SHIFTED_OUTPUT
#elif SABER_DISPLAY == SABER_DISPLAY_SEGMENT
ShiftedSevenSegment shifted7;
Digit4UI digit4UI;
#define SHIFTED_OUTPUT
#endif

#if SABER_DISPLAY == SABER_DISPLAY_128_32
void BlockDrawOLED(const BlockDrawChunk* chunks, int n)
{
    // The renderer assumes clear to black beforehand.
    // But does still support drawing in black.
    for (int i = 0; i < n; ++i) {
        const BlockDrawChunk& chunk = chunks[i];

        // Simple for the single row.
        int row = chunk.y >> 3;
        int bit = chunk.y - (row << 3);
        uint8_t mask = 1 << bit;
        uint8_t* p = oledBuffer + (row << OLED_WIDTH_SHIFT) + chunk.x0;

        if (chunk.color) {
            for (int nPix = chunk.x1 - chunk.x0; nPix > 0; nPix--, p++) {
                *p |= mask;
            }
        }
        else {
            for (int nPix = chunk.x1 - chunk.x0; nPix > 0; nPix--, p++) {
                *p &= ~mask;
            }
        }
    }
}
#endif

void setupManifestData()
{
    MemPalette memPalette[NUM_PALETTES];

    spiFlash.readMemory(0, (uint8_t*) manifest.getBasePtr(), MemImage::SIZE_MEMUNITS);
    spiFlash.readMemory(Manifest::PaletteAddr(0), (uint8_t*) memPalette, MemImage::SIZE_PALETTE);
    spiFlash.readMemory(Manifest::DescAddr(), (uint8_t*) cmdParser.desc.c_str(), MemImage::SIZE_DESC);
    
    for(int i=0; i<NUM_PALETTES; ++i) {
        SaberDB::Palette pal;
        pal.soundFont = memPalette[i].soundFont;
        pal.bladeColor.r = memPalette[i].bladeColor.r;
        pal.bladeColor.g = memPalette[i].bladeColor.g;
        pal.bladeColor.b = memPalette[i].bladeColor.b;
        pal.impactColor.r = memPalette[i].impactColor.r;
        pal.impactColor.g = memPalette[i].impactColor.g;
        pal.impactColor.b = memPalette[i].impactColor.b;
        saberDB.setPalette(i, pal);
    }
}

void setup() 
{
#if defined(SHIFTED_OUTPUT)
        // I'm a little concerned about power draw on the display, in some states.
        // Do this first thing - set all the pins to ground so they don't short / draw.
        pinMode(PIN_LATCH, OUTPUT);
        pinMode(PIN_CLOCK, OUTPUT);
        pinMode(PIN_DATA, OUTPUT);

        digitalWrite(PIN_LATCH, HIGH);
        digitalWrite(PIN_CLOCK, LOW);
        digitalWrite(PIN_DATA, LOW);

        digitalWrite(PIN_LATCH, LOW);
        shiftOut(PIN_DATA, PIN_CLOCK, MSBFIRST, 0);
        shiftOut(PIN_DATA, PIN_CLOCK, MSBFIRST, 0);
        digitalWrite(PIN_LATCH, HIGH);
    #endif

    InitPWM();
    Serial.begin(19200);  // Still need to turn it on in case USB is connected later to configure or debug.
    #if SERIAL_DEBUG == 1
    {
        int nTries = 0;
        while (!Serial) {
            delay(200);
            ++nTries;
            ledA.set((nTries & 1) ? true : false);
        }
        Log.attachSerial(&Serial);
    }
    #endif

    Log.p("Setup:").eol(); 
    Log.p("Init flash memory.").eol();

    flashTransport.begin();
    spiFlash.begin();
    setupManifestData();

    Log.p("Init audio system.").eol();
    i2sAudioDriver.begin();

    Log.p("Init accelerometer and magnemometer.").eol();
    delay(10);
    accelMag.begin(&SPI);
    accelMag.flushAccel(0);
    //Log.p("Min/Max=").v3(accelMag.getMagMin()).p(" ").v3(accelMag.getMagMax()).eol();
    delay(10);

    Log.p("Init systems.").eol();
    analogReadResolution(12);
    analogReference(AR_INTERNAL1V65);
    voltmeter.begin();
    delay(10);
    bladePWM.setRGB(RGB::BLACK);

    buttonA.setHoldHandler(buttonAHoldHandler);
    buttonA.setClickHandler(buttonAClickHandler);
    buttonA.setReleaseHandler(buttonAReleaseHandler);

    tester.attach(&buttonA);
    tester.attachDB(&saberDB, &bladePWM, &bladeColor);

    Log.p("Average power: ").p(voltmeter.averagePower()).eol();
    bladePWM.setVoltage(voltmeter.averagePower());

    Log.p("Init display.").eol();

    #if SABER_DISPLAY == SABER_DISPLAY_128_32
    {
        display.begin(OLED_WIDTH, OLED_HEIGHT, SSD1306_SWITCHCAPVCC);
        vRender.Attach(BlockDrawOLED);
        vRender.SetSize(OLED_WIDTH, OLED_HEIGHT);
        vRender.SetClip(VRender::Rect(0, 0, OLED_WIDTH, OLED_HEIGHT));
        vRender.Clear();

        renderer.Attach(OLED_WIDTH, OLED_HEIGHT, oledBuffer);
        Log.p("OLED display connected.").eol();
    }
    #elif SABER_DISPLAY == SABER_DISPLAY_7_5
    {
        // No pin 6
        // Pin 7 - decimal point - not used
        const uint8_t cols[] = { 5, 1, 9, 15, 14};
        dotMatrix.attachCol(5, cols);
        const uint8_t rows[] = { 2, 13, 3, 4, 12, 11, 10};
        dotMatrix.attachRow(7, rows);

        Log.p("Shifted dot matrix 5x7 init.").eol();
    }
    #elif SABER_DISPLAY == SABER_DISPLAY_SEGMENT
    {
        const uint8_t digit[] = {10, 4, 13, 15};
        shifted7.attachDigit(4, digit);
        const uint8_t segment[] = {6, 5, 12, 2, 11, 3, 1, 14};
        shifted7.attachSegment(8, segment);

        Log.p("Shifted seven digit init.").eol();
    }
    #endif

#if ITSY_DOTSTAR_UI()
    {
        oneDotstar.beginSW(40, 41);
        Log.p("Itsy dotstar initialized.").eol();
    }
#   endif

    #if defined(SABER_NUM_LEDS)
    {
        dotstar.beginSPI(PIN_DOTSTAR_EN);
        dotstar.setConfig( SABER_DOTSTAR_CONFIG() );
        Log.p("SPI Dotstar initialized.").eol();
}
    #endif

    sfx.setVolume(VOLUME_1);
    changePalette(0);
    ledA.set(true); // "power on" light

    buttonA.setHoldRepeats(true);  // everything repeats!!

    Log.p("Setup() done.").eol();
}

void changePalette(int index)
{
#ifdef SABER_SOUND_ON
    // The SD card memory streaming and the use of the SD
    // file system lead to crashes. (Grr.) Stop the sound
    // here to see if it cleans up the problem.
    sfx.stopSound();
#endif

    saberDB.setPalette(index);
    const SaberDB::Palette *palette = saberDB.getPalette();

    sfx.setFont(saberDB.soundFont());
    bladeColor.setBladeColor(palette->bladeColor);
    bladeColor.setImpactColor(palette->impactColor);
}

void buttonAReleaseHandler(const Button&)
{
    ledA.blink(I2SAudioDriver::stableSlowTime(), 0, 0);
    ledA.set(true); // power is on.
}

bool setPaletteFromHoldCount(int count)
{
    changePalette(count - 1);
    return count <= NUM_PALETTES;
}

bool setVolumeFromHoldCount(int count)
{
    sfx.setVolume(SaberDB::toVolume256(count - 1));
    return count >= 0 && count <= NUM_VOLUMES + 1;
}

bool setLockFromHoldCount(int count)
{
    lockOn = count > 1;
    return count <= 2;
}

void igniteBlade()
{
    if (bladeStateManager.canIgnite()) {
        bladeStateManager.ignite(sfx.getIgniteTime());
        if (sfx.smoothMode())
            sfx.sm_ignite();
        else
            sfx.playSound(SFX_POWER_ON, SFX_OVERRIDE);
    }
}

void retractBlade()
{
    if (bladeStateManager.canRetract()) {
        bladeStateManager.retract(sfx.getRetractTime());
        if (sfx.smoothMode())
            sfx.sm_retract();
        else
            sfx.playSound(SFX_POWER_OFF, SFX_OVERRIDE);
    }
}

// One button case.
void buttonAClickHandler(const Button&)
{
    uiMode.setActive(I2SAudioDriver::stableSlowTime());

    Log.p("buttonAClickHandler").eol();
    if (bladeStateManager.isOff()) {
        uiMode.nextMode();
        // Turn off blinking so we aren't in a weird state when we change modes.
        ledA.blink(I2SAudioDriver::stableSlowTime(), 0, 0, 0);
        // Blink the power level
        if (uiMode.mode() == UIMode::NORMAL) {
            int power = UIRenderData::powerLevel(voltmeter.averagePower(), NUM_VOLUMES);
            ledA.blink(I2SAudioDriver::stableSlowTime(), power, INDICATOR_CYCLE, 0, LEDManager::BLINK_LEADING);
        }
    }
    else if (bladeStateManager.state() == BladeState::kOn) {
        if (lockTimer.enabled()) {
            if (lockTimer.click())
                retractBlade();
        }
        else {
            uint32_t stable = I2SAudioDriver::stableSlowTime();
            bladeColor.doFlash(stable);
            if (sfx.smoothMode())
                sfx.sm_playEvent(SFX_USER_TAP);
            else
                sfx.playSound(SFX_USER_TAP, SFX_GREATER_OR_EQUAL);
        }    
    }
}

void buttonAHoldHandler(const Button& button)
{
    uiMode.setActive(I2SAudioDriver::stableSlowTime());
    //Log.p("buttonAHoldHandler nHolds=").p(button.nHolds()).eol();
    
    if (bladeStateManager.isOff()) {
        bool buttonLEDOn = false;
        int cycle = button.cycle(&buttonLEDOn);

        if (uiMode.mode() == UIMode::NORMAL) {
            if (button.nHolds() == 1) {
                igniteBlade();
            }
        }
        else 
        {
            if (buttonLEDOn) {
                if (uiMode.mode() == UIMode::PALETTE) {
                    if (!setPaletteFromHoldCount(cycle))
                        buttonLEDOn = false;
                }
                else if (uiMode.mode() == UIMode::VOLUME) {
                    if (!setVolumeFromHoldCount(cycle))
                        buttonLEDOn = false;
                }
                else if (uiMode.mode() == UIMode::LOCK) {
                    if (!setLockFromHoldCount(cycle))
                        buttonLEDOn = false;
                }
            }
        }
        ledA.set(buttonLEDOn);
    }
    else if (bladeStateManager.canRetract()) {
        if (button.nHolds() == 1) {
            if (lockOn)
                lockTimer.start();
            else
                retractBlade();
        }
    }
}


void processSerial() 
{
    while (Serial.available()) {
        int c = Serial.read();
        cmdParser.push(c);
    }
}
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
void loop() {
    static ProfileData data("loop");
    ProfileBlock block(&data);
    static uint32_t lastLoopTime = 0;

    // processSerial() doesn't seem to get called on M0 / ItsyBitsy. 
    // Not sure why.
    // processSerial() is intended to be "out of loop". Call it
    // first in the loop to try to preserve current behavior.
    processSerial();

    const uint32_t msec = millis();
    const uint32_t msecStable = I2SAudioDriver::stableSlowTime();

    if (lastLoopTime == 0) {
        lastLoopTime = msec - 1;
    }
    uint32_t delta = msec - lastLoopTime;
    lastLoopTime = msec;

/*
    if (msec - lastPrintTime >= 500) {
        Log.p("msec=").p(msec).eol();
        lastPrintTime = msec;
    }
*/
    tester.process();
    buttonA.process(msec);
    lockTimer.tick(delta);

#ifdef SABER_UI_IDLE_MEDITATION_LED_OFF
    if (uiMode.mode() == UIMode::NORMAL && bladeStateManager.isOff() && uiMode.isIdle(msec)) {
        int pwm = 255;
        ledProp.tick(delta, &pwm);
        PWMWrite(ledA.pin(), (uint8_t)pwm);
    } 
    else {
        ledProp.start(1000, 255, 0);
        ledA.process();
    }
#else
    ledA.process(I2SAudioDriver::stableSlowTime());
#endif

    processAccel(msec);

    {
        static uint32_t lastMsecStable = 0;
        if (lastMsecStable != msecStable) {
            lastMsecStable = msecStable;

            // Get the normal or flash color of blade (ignoring the ignite, retract, power)
            // Modify the blade color for ignite / retract (ignoring power)
            // Apply the power setting.
            bladeColor.tick(msecStable);
            osbr::RGB color = bladeStateManager.process(bladeColor.getColor(), msecStable);
            bladePWM.setRGB(color);
            //Log.p("pwm=").p(bladePWM.pwmVal(0)).p(" ").p(bladePWM.pwmVal(1)).p(" ").p(bladePWM.pwmVal(2)).eol();
        }
    }

    bool stillReset = sfx.process(bladeStateManager.state(), delta);
    if (stillReset) {
        #if SABER_ACCELEROMETER == SABER_ACCELEROMETER_LSM303
        accelMag.recalibrateMag();
        swing.setOrigin();
        #endif
    }

    // Timing / skip is in the voltmeter class.
    voltmeter.takeSample(msecStable);
    bladePWM.setVoltage(voltmeter.averagePower());
    loopDisplays(msecStable);
}

void loopDisplays(uint32_t msecStable)
{
    static ProfileData data("loopDisplays");
    ProfileBlock block(&data);

    UIRenderData uiRenderData;
    uiRenderData.volume = SaberDB::toVolume4(sfx.getVolume());
    uiRenderData.color = BladePWM::convertRawToPerceived(bladeColor.getBladeColor());
    uiRenderData.palette = saberDB.paletteIndex();
    uiRenderData.mVolts = voltmeter.easedPower();
    uiRenderData.fontName = manifest.getUnit(sfx.currentFont()).name;
    uiRenderData.soundBank = sfx.currentFont();
    uiRenderData.locked = lockOn;
    uiRenderData.lockFlash = lockTimer.dark();

    bool normalModeAndOff = uiMode.mode() == UIMode::NORMAL && bladeStateManager.isOff();
    (void)normalModeAndOff;

    // Single dotstar on the microcontroller.
#if ITSY_DOTSTAR_UI()
    {
        osbr::RGBA itsyRGBA;
        static osbr::RGBA itsyLED = 0;

        // FIXME: what is the acceptable brightneess range?
        oneDotstarUI.Process(&itsyRGBA, 1, 128, 
            msecStable, uiMode.mode(), !bladeStateManager.isOff(), uiRenderData);
        if (itsyRGBA != itsyLED) {
            itsyLED = itsyRGBA;
            oneDotstar.display(&itsyLED, 1);
        }
    }
#endif // ITSY_DOTSTAR_UI

    // ------------ LEDs ---------- //
#if defined(SABER_NUM_LEDS)
    osbr::RGBA rgba[SABER_NUM_LEDS] = {0};

#   if defined(SABER_UI_START)
    {
#       if defined(SABER_UI_IDLE_MEDITATION)
        if (normalModeAndOff && uiMode.isIdle(msec)) {
            dotstarUI.Process(rgba + SABER_UI_START, SABER_UI_COUNT, SABER_UI_BRIGHTNESS, 
                msecStable, UIMode::MEDITATION, false, uiRenderData);
            rgba[SABER_UI_START + SABER_UI_COUNT - 1] = osbr::RGBA(uiRenderData.color, SABER_UI_BRIGHTNESS);
        }
        else
#       endif // SABER_UI_IDLE_MEDITATION
        {
            dotstarUI.Process(rgba + SABER_UI_START, SABER_UI_COUNT, SABER_UI_BRIGHTNESS, 
                msecStable, uiMode.mode(), !bladeStateManager.isOff(), uiRenderData);
        }

#       if defined(SABER_UI_FADE_OUT)
        if (normalModeAndOff && uiMode.isIdle(msecStable)) {
            static const uint32_t FADE_TIME = 800;
            uint32_t over = uiMode.millisPastIdle(msecStable);
            float fraction = 0;

            if (over < FADE_TIME) {
                fraction = (FADE_TIME - over) / float(FADE_TIME);
            }
            for(int i=SABER_UI_START; i < SABER_UI_START + SABER_UI_COUNT; ++i) {
                rgba[i].r = uint8_t(fraction * rgba[i].r);
                rgba[i].g = uint8_t(fraction * rgba[i].g);
                rgba[i].b = uint8_t(fraction * rgba[i].b);
            }
        }
#       endif  // SABER_UI_FADE_OUT
#       if defined(SABER_UI_REVERSE)
            for(int i=0; i < SABER_UI_COUNT/2; ++i) {
                glSwap(rgba[i + SABER_UI_START], SABER_UI_START + SABER_UI_COUNT - 1 - i);
            }
#       endif // SABER_UT_REVERSE
    }
#   endif // SABER_UI_START
#   if defined(SABER_CRYSTAL_START)
    {
        if (normalModeAndOff) {
            osbr::RGB rgb;
            calcCrystalColorHSV(msecStable, bladeColor.getBladeColor(), &rgb);
            rgba[SABER_CRYSTAL_START].set(rgb, SABER_CRYSTAL_BRIGHTNESS);
        }
        else {
            rgba[SABER_CRYSTAL_START].set(bladeColor.getBladeColor(), SABER_CRYSTAL_BRIGHTNESS);
        }
    }
#   endif // SABER_CRYSTAL_START
#   if defined(SABER_FLASH_LED)
    {
        // Flashes a secondary LED with the flash on clash color.
        RGB flashColor = saberDB.impactColor();
        rgba[SABER_FLASH_LED] = ((bladeStateManager.state() == BLADE_FLASH) ? flashColor : RGBA::BLACK, 255);
    }
#   endif // SABER_FLASH_LED

    /* FIXME not sure caching needed. Turned it off, seems fine
    static osbr::RGBA leds[SABER_NUM_LEDS] = {0};
    bool send = false;

    for (int i = 0; i < SABER_NUM_LEDS; ++i) {
        if (leds[i] != rgba[i]) {
            leds[i] = rgba[i];
            send = true;
        }
    }
    if (send) {
        dotstar.display(leds, SABER_NUM_LEDS);
    }
    */
    dotstar.display(rgba, SABER_NUM_LEDS);
#endif // SABER_NUM_LEDS

#if SABER_DISPLAY == SABER_DISPLAY_128_32
    {
        switch (renderStage)
        {
        case 0:
            memset(oledBuffer, 0, OLED_HEIGHT * OLED_WIDTH / 8);
            vRender.Clear();
            vRender.ClearTransform();
            break;
        case 1:
            vectorUI.Draw(&vRender, &renderer,
                msec, delta, uiMode.mode(), 
                !bladeStateManager.bladeOff(), &uiRenderData);
            break;
        case 2:
            display.display(oledBuffer);
            break;
        }
        renderStage++;
        if (renderStage == 3)
            renderStage = 0;
    }
#endif

#if SABER_DISPLAY == SABER_DISPLAY_7_5
    {
        display75.Draw(msec, uiMode.mode(), !bladeStateManager.bladeOff(), &uiRenderData);
        dotMatrix.setFrom7_5(display75.Pixels());
    }
#elif SABER_DISPLAY == SABER_DISPLAY_SEGMENT
    {
        digit4UI.Draw(uiMode.mode(), &uiRenderData);
        shifted7.set(digit4UI.Output().c_str());
    }
#endif

// Now loop() the specific display.
#if SABER_DISPLAY == SABER_DISPLAY_7_5
    {
        uint8_t a = 0, b = 0;
        dotMatrix.loop(micros(), &a, &b);

        // For columns / anodes.
        //uint16_t bits = 0;  // all rows
        //bits |= (1<<5); // column 1
        //bits |= (1<<1); // column 2qq
        //bits |= (1<<9); // column 3 - note the bit skip!! pin 8
        //bits |= (1<<15); // column 4
        //bits |= (1<<14); // column 5

        /*
            // For rows / cathodes.
            uint16_t bits = ~((1<<1) | (1<<9) | (1<<15) | (1<<14));
            //bits ^= (1<<2);
            //bits ^= (1<<13);
            //bits ^= (1<<3);
            //bits ^= (1<<4);
            //bits ^= (1<<12);
            //bits ^= (1<<11);
            bits ^= (1<<10);
            */

        //a = bits & 0xff;
        //b = bits >> 8;

        digitalWrite(PIN_LATCH, LOW);
        shiftOut(PIN_DATA, PIN_CLOCK, MSBFIRST, a);
        shiftOut(PIN_DATA, PIN_CLOCK, MSBFIRST, b);
        digitalWrite(PIN_LATCH, HIGH);

        // digitalWrite(PIN_LATCH, LOW);
        // digitalWrite(PIN_CLOCK, LOW);
        // digitalWrite(PIN_DATA, HIGH);
    }
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

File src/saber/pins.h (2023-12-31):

/*
  Copyright (c) Lee Thomason, Grinning Lizard Software

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
  THE SOFTWARE IS PROVIDED "AS IS", WITHOUT WARRANTY OF ANY KIND, EXPRESS OR
  IMPLIED, INCLUDING BUT NOT LIMITED TO THE WARRANTIES OF MERCHANTABILITY,
  FITNESS FOR A PARTICULAR PURPOSE AND NONINFRINGEMENT. IN NO EVENT SHALL THE
  AUTHORS OR COPYRIGHT HOLDERS BE LIABLE FOR ANY CLAIM, DAMAGES OR OTHER
  LIABILITY, WHETHER IN AN ACTION OF CONTRACT, TORT OR OTHERWISE, ARISING FROM,
  OUT OF OR IN CONNECTION WITH THE SOFTWARE OR THE USE OR OTHER DEALINGS IN THE
  SOFTWARE.
*/

#ifndef PINS_HEADER
#define PINS_HEADER

#include <stdint.h>

// --- Configuration ---
// Note: Serial connection should be set to 19200 baud with a newline after commands.

#define SABER_MODEL_TEST			255
#define SABER_MODEL_GECKO			1	// PCB, Teensy 3, external amp and accel
#define SABER_MODEL_BLACK			2	// PCB, Prop Shield, Teensy 3, Dotstar UI
//#define SABER_MODEL_SHOCK			3	// PCB, Prop Shield, Teensy 3, OLED. Dropped; heatsink crushed carriage when I dropped it. Become SHOCK2.
#define SABER_MODEL_SILVER_SHOCK	4	// PCB, Prop Shield, Teensy 3
//#define SABER_MODEL_BO			5	// 2 button prop shield Never finished
//#define SABER_MODEL_PROTO 		6	// Burned out; never needed to rebuild.
#define SABER_MODEL_TANO 			7
//#define SABER_MODEL_SISTER 		8	// Shield v3, Teensy 3.5, RF24 communication
#define SABER_MODEL_AQUATIC			9
#define SABER_MODEL_SHOCK2		   10	// Shield v3, Teensy 3.5, Dotstar, Display (woh)
#define SABER_MODEL_VIGILANCE	   11	// Shield v4, Teensy 3.5, Dotstar crystals, bubble display AKA Tali
#define SABER_MODEL_AHSOKA		   12
#define SABER_MODEL_GREEN_SKY	   13
#define SABER_MODEL_TANO_2 		   14   // Shield v4, Teensy 3.5, Dotstar UI
#define SABER_MODEL_SISTER_2	   15   // Shield v4, Teensy 3.5, 5x7 Display. Replaced the cool-but-useless wirelss communication
#define SABER_MODEL_KENOBI_IV	   16   // ItsyBitsy, Shield v1, Neopixel
#define SABER_MODEL_AQUATIC_2	   17   // ItsyBitsy, Shield v1c, Dotstar
#define SABER_MODEL_TYVOKKA		   18   // ItsyBitsy, Shield v1c, Dotstar
//#define SABER_MODEL_SHOCK3  	   19   // Itsy v2b, OLED (128x32), Dotstar crystal
#define SABER_MODEL_LEIA  	   	   20   // Itsy, Dotstar UI
#define SABER_MODEL_SISTERS2  	   21   // Itsy, OLED (128x32)
//#define SABER_MODEL_DUCHESS   	   22   // original (rebuilt)
#define SABER_MODEL_PROTECTION 	   23   // Itsy, Dotstar UI
#define SABER_MODEL_CLAN		   24	// Itsy, one LED UI
#define SABER_MODEL_LEIA_PS		   25	// Itsy, one LED UI, essentially a clan saber
#define SABER_MODEL_DUCHESS   	   27   // Itsy 4a, Dotstar UI, LSM6D Gyro
#define SABER_MODEL_DARKSABER	   28   // Itsy 4a, Dotstar UI, LSM6D Gyro
#define SABER_MODEL_VADER	   	   29   // Itsy 4, Dotstar UI, LSM6D Gyro
#define SABER_MODEL_KENOBI_IV2	   30   // Itsy 4, Dotstar UI, LSM6D Gyro
#define SABER_MODEL_VIGILANCE2	   31   // Itsy 4, Dotstar UI, LSM6D Gyro

#define SABER_SUB_MODEL_NONE		0
#define SABER_SUB_MODEL_LUNA		1
#define SABER_SUB_MODEL_CELESTIA	2
#define SABER_SUB_MODEL_SHOTO       3
#define SABER_SUB_MODEL_STANDARD    4
#define SABER_SUB_MODEL_APPRENTICE	5	// Silver "test". Unmodified ultra-sabers case.
#define SABER_SUB_MODEL_BLACK		6
#define SABER_SUB_MODEL_INITIATE    7
#define SABER_SUB_MODEL_PROPHECY    8	// There is no way to tell the prophecies apart...so...this will need to be reconciled & merged.
//#define SABER_SUB_MODEL_PROPHECY_2  9	
#define SABER_SUB_MODEL_AEON        10
#define SABER_SUB_MODEL_APP_LE      11
#define SABER_SUB_MODEL_A			12
#define SABER_SUB_MODEL_B			13

// ----------------------------------
#define SERIAL_DEBUG 				1
#define SABER_MODEL 				SABER_MODEL_VIGILANCE2
#define SABER_SUB_MODEL				0
// ----------------------------------

#define SABER_SOUND_SD 				1	// external memory card
#define SABER_SOUND_FLASH 			2	// M0 memory

#define SABER_DISPLAY_128_32		1
// #define SABER_DISPLAY_7_5_DEPRECATED 2	// NON shifted. So many wires. So many.
#define SABER_DISPLAY_SEGMENT		3	// Shifted
#define SABER_DISPLAY_7_5 			4	// Shifted

#define SABER_LED_NEOPIXEL			1
#define SABER_LED_DOTSTAR			2

#define PCB_VERSION_1				1   // PCB, Teensy 3.2, external amp and accel
#define PCB_VERSION_5				5   // PCB, Prop Shield, Teensy 3.2, OLED (VERIFY)
#define PCB_VERSION_7				7	// Split PCB. Prop shield. Teensy 3.5.
#define PCB_VERSION_9				9   // Split PCB. Prop shield. Teensy 3.5.
#define PCB_SHIELD_2			   12	// Grinliz shield + Teensy 3.5
#define PCB_SHIELD_3			   13	
#define PCB_SHIELD_4			   14	
#define PCB_SHIELD_5			   15
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

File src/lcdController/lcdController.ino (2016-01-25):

/*
Copyright (c) 2016 Lee Thomason, Grinning Lizard Software

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
THE SOFTWARE IS PROVIDED "AS IS", WITHOUT WARRANTY OF ANY KIND, EXPRESS OR 
IMPLIED, INCLUDING BUT NOT LIMITED TO THE WARRANTIES OF MERCHANTABILITY, 
FITNESS FOR A PARTICULAR PURPOSE AND NONINFRINGEMENT. IN NO EVENT SHALL THE 
AUTHORS OR COPYRIGHT HOLDERS BE LIABLE FOR ANY CLAIM, DAMAGES OR OTHER 
LIABILITY, WHETHER IN AN ACTION OF CONTRACT, TORT OR OTHERWISE, ARISING FROM, 
OUT OF OR IN CONNECTION WITH THE SOFTWARE OR THE USE OR OTHER DEALINGS IN THE 
SOFTWARE.
*/

#include <Grinliz_Arduino_Util.h>
#include <Button.h>
#include <SoftwareSerial.h>
#include <Wire.h>
#include <LiquidCrystal.h>
#include "widget.h"

#define SERIAL_DEBUG

//              rs, enable, d0, d1, d2, d3
// ON LCD:        4,  6,  11, 12, 13, 14
LiquidCrystal lcd(10, 11, A1, A0, 13, 12);

CStr<24> serialBuffer;
bool connectionOK = true;
uint32_t lastConnect = 0;

enum {
  WELCOME_SCREEN,
  CONFIG_SCREEN,
  PALETTE_SCREEN,
  SENSOR_SCREEN,
  NUM_SCREENS
};

int currentScreen = WELCOME_SCREEN;
int focus = 0;

TextWidget welcomeText(         WELCOME_SCREEN, 0, 0, "Grinning Lizard ");
TextWidget companyText(         WELCOME_SCREEN, 0, 1, "   Open Saber"   );

TextNumWidget audio(            CONFIG_SCREEN,  0,  0, "audio:", 1, "aud", Widget::TYPE_INT);
TextNumWidget volume(           CONFIG_SCREEN,  9,  0, "vol:", 3, "vol", Widget::TYPE_INT);
TextNumWidget motion(           CONFIG_SCREEN,  0,  1, "m:",   4, "mot", Widget::TYPE_FLOAT);
TextNumWidget impact(           CONFIG_SCREEN,  10, 1, "i:",   4, "imp", Widget::TYPE_FLOAT);

TextNumWidget   volts(          SENSOR_SCREEN,  8,  0, "vcc:", 4, "vcc", Widget::TYPE_FLOAT);
PercentX3Widget utilization(    SENSOR_SCREEN,  0,  1, "util:", "util");

TextNumWidget palette(          PALETTE_SCREEN, 0,  0, "P:",   1, "pal", Widget::TYPE_INT);
TextNumWidget power(            PALETTE_SCREEN, 9,  0, "mA:",  4, "amp", Widget::TYPE_INT);
TextNumWidget bladeColorRed(    PALETTE_SCREEN, 0,  1, "#",    2, 0,     Widget::TYPE_HEX);
TextNumWidget bladeColorGreen(  PALETTE_SCREEN, 3,  1, 0,      2, 0,     Widget::TYPE_HEX);
TextNumWidget bladeColorBlue(   PALETTE_SCREEN, 5,  1, 0,      2, 0,     Widget::TYPE_HEX);
TextNumWidget impactColorRed(   PALETTE_SCREEN, 9,  1, "#",    2, 0,     Widget::TYPE_HEX);
TextNumWidget impactColorGreen( PALETTE_SCREEN, 12, 1, 0,      2, 0,     Widget::TYPE_HEX);
TextNumWidget impactColorBlue(  PALETTE_SCREEN, 14, 1, 0,      2, 0,     Widget::TYPE_HEX);

Widget* widgetArr[] = {
  &welcomeText,
  &companyText,

  &audio,
  &volume,
  &motion,
  &impact,

  &volts,
  &utilization,

  &palette,
  &power,
  &bladeColorRed, &bladeColorGreen, &bladeColorBlue,
  &impactColorRed, &impactColorGreen, &impactColorBlue,
};

static const int NUM_WIDGETS = sizeof(widgetArr) / sizeof(widgetArr[0]);

SoftwareSerial softSerial(12, 13);

Stream* debugSerial = 0;
Stream* saberSerial = 0;

Button buttonUp(3);
Button buttonDown(4);
Button buttonLeft(5);
Button buttonRight(6);
Button buttonInc(A5);
Button buttonDec(A4);

void setup() {
  lcd.begin(16, 2);
  lcd.print("Initializing...");

  Serial.begin(19200);
  softSerial.begin(19200);

  debugSerial = &Serial;
  saberSerial = &softSerial;

  lcd.setCursor(7, 0);
  lcd.noAutoscroll();

  focus = 0;
  drawScreen(currentScreen);

  delay(100);
  if (debugSerial) {
    debugSerial->println("controller setup");
  }
  lastConnect = millis();
}

void connect() {
  uint32_t delta = millis() - lastConnect;
  if (delta > 400) {
    if (debugSerial) {
      debugSerial->println("trying to connect...");
    }
    saberSerial->print("stat\n");
    lastConnect = millis();
  }
}

uint32_t lastTime = 0;

void loop() {
  buttonUp.process();
  buttonDown.process();
  buttonLeft.process();
  buttonRight.process();
  buttonInc.process();
  buttonDec.process();

  bool processed = flushSerial();
  if (processed) {
    drawScreen(currentScreen);
  }

  if (!connectionOK) {
    connect();
  }
  if (!connectionOK) {
    return;
  }

  if (buttonDown.press()) {
    debugSerial->println("downPress");
    focusDelta(1);
  }
  if (buttonUp.press()) {
    debugSerial->println("upPress");
    focusDelta(-1);
  }
}

bool flushSerial() {
  bool processed = false;
  uint8_t color[3];

  while (saberSerial->available()) {
    int c = saberSerial->read();
    if (debugSerial) {
      debugSerial->write(c);
    }
    if (c == '\n') {
      static const int PREFIX_LEN = 3;
      static const char* PREFIX = "[-]";
      if (memcmp(serialBuffer.c_str(), PREFIX, PREFIX_LEN) == 0) {
        if (!connectionOK) {
          connectionOK = true;
        }
        const char* cmd = serialBuffer.c_str() + PREFIX_LEN;

        for (int i = 0; i < NUM_WIDGETS; ++i) {
          widgetArr[i]->handleInput(cmd);
        }
        if (memcmp(cmd, "bc #", 4) == 0) {
          parseNHex(cmd + 4, color, 3);
          if (debugSerial) {
            debugSerial->print("bc ");
            debugSerial->print(color[0], HEX);
            debugSerial->print(" ");
            debugSerial->print(color[1], HEX);
            debugSerial->print(" ");
            debugSerial->println(color[2], HEX);
          }
          bladeColorRed.setIVal(color[0]);
          bladeColorGreen.setIVal(color[1]);
          bladeColorBlue.setIVal(color[2]);
        }
        if (memcmp(cmd, "ic #", 4) == 0) {
          parseNHex(cmd + 4, color, 3);
          if (debugSerial) {
            debugSerial->print("ic ");
            debugSerial->print(color[0], HEX);
            debugSerial->print(" ");
            debugSerial->print(color[1], HEX);
            debugSerial->print(" ");
            debugSerial->println(color[2], HEX);
          }
          impactColorRed.setIVal(color[0]);
          impactColorGreen.setIVal(color[1]);
          impactColorBlue.setIVal(color[2]);
        }
      }
      serialBuffer.clear();
      processed = true;
    }
    else {
      serialBuffer.append(c);
    }
  }
  return processed;
}
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

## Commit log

2017-01-25 working on gecko next
    [buttress.scad, dim.scad, unified.scad]
2017-01-26 new design for prophecy
    [buttress.scad, dim.scad, unifiedNotchless.scad]
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2017-01-28 integrate beam into prohpecy
    [beam.scad, buttress.scad, unified.scad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]
2017-01-28 new pcb design wip
    [unifiedNotchless.scad]
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2017-01-31 some tweaks to prophecy design
    [dim.scad, unifiedNotchless.scad]
2017-02-02 7b ordered. fix build on refactoring changes.
    [unifiedNotchless.scad]
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2017-02-17 tweaks for new boards
    [dim.scad]
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2017-02-22 fix some sound support macros
    [pins.h, saber.ino]
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2017-03-09 pcb and parts work
    [beam.scad, buttress.scad, dim.scad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]
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2017-03-12 tweaks to dotstar. testing prophecy
    [unifiedNotchless.scad]
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2017-03-14 split into 3.2 and 3.5 versions
    [unified32.scad, unified35.scad]
2017-03-14 tweaks to 3.5 parts
    [unified35.scad]
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2017-03-16 trying to overcome warping
    [unified35.scad]
2017-03-26 fixes and tweaks for tano 1
    [dim.scad, unified35.scad]
2017-03-26 harden to sound failure
    [buttress.scad, dim.scad, unified.scad]
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2017-04-28 tweaks to design and bug fixes
    [dim.scad, unified35.scad]
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2017-04-28 fix on/off bug, fix 'delayed readout' bug
    [saber.ino]
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2017-05-15 correct resistor values
2017-05-15 missing files
    [buttonPlug.scad, key.scad, sm_key.scad]
2017-05-16 convert to perceived color. fix a bunch of formatting.
    [saber.ino]
2017-05-21 wip on ui testing
    [dim.scad]
2017-05-22 improved testing code. accel fixes.
    [dotstar.ino, pins.h, saber.ino]
2017-05-27 new parts for sisters design
    [beam.scad, buttress.scad, dim.scad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]
2017-05-30 initial work on sisters
    [unified35.scad]
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2017-06-08 update to the sister's unified design.
    [dim.scad, unified35.scad]
2017-06-11 working on sisters design
    [dim.scad, unified35.scad]
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2017-06-13 experimental beam wobble
    [beam.scad, unified35.scad]
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2017-06-14 minor tweaks, fixes, organization
    [saber.ino]
2017-06-18 tweaking the sister design
    [beam.scad, dim.scad, unified35.scad]
2017-06-21 more tweaks for sister design
    [dim.scad, unified35.scad]
2017-06-30 remove tano, replace with tano2
    [pins.h]
2017-06-30 trying to fix bugs, get sister-c working.
    [pins.h, saber.ino]
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2017-07-13 initial sister code working. wow.
    [dim.scad]
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2017-07-14 fix compile errors on different saber models
    [saber.ino]
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2017-07-19 test greeble for sisters. 1st pass at ref card generator
    [greeble24.scad]
2017-07-19 new version of the greeble
    [greeble24.scad]
2017-07-20 aesthetic tweak to the greeble
    [greeble24.scad]
2017-07-21 initial version of refcard
    [unified35.scad]
2017-07-27 new part for sisters
    [dim.scad, unified35.scad]
2017-07-29 debugging the amp circuit. first pass at shield v2
    [dim.scad, unified.scad, unified35.scad]
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2017-08-02 first pass at shock v2
    [dim.scad, emitter.scad, unified.scad]
2017-08-13 add extender for cnc
    [extender.scad]
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2017-08-17 tweaks to v3 shield and parts for sisters
    [extender.scad]
2017-08-22 tweaked sisters, v3 shield (ordered)
    [greeble24.scad]
2017-08-23 rewrite of the sisters chassis
    [buttress.scad, dim.scad, unified35.scad]
2017-08-24 fix the connection from the locking ring to buttress 0
    [unified35.scad]
2017-08-25 adding forward circuit board for cnc
    [unified35.scad]
2017-08-28 fixes for the new v3 arch
    [pins.h]
2017-08-28 tweaking the sisters design
    [unified35.scad]
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2017-09-06 working on the swoop
    [swoop.scad]
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2017-09-16 big update to sisters design to accomodate mid-body pcb, reduce support structure, and switch the micro-controller to the v3 shield.
    [buttress.scad, dim.scad, unified35.scad]
2017-09-16 tweaks to sisters chassis
    [unified35.scad]
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2017-09-25 testing luna. many fixes. switch to software role for rf24.
    [pins.h, saber.ino]
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2017-09-27 tweaks to unified35. check in green matrix code
    [unified35.scad]
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2017-10-05 tweaks for luna and celestia. fix LED timer
    [saber.ino]
2017-10-06 fix teensy bug with analog vs. digital write. clean up ui and LED blinking.
    [saber.ino]
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2017-10-21 tweaks and fixes for sisters and aquatic
    [dim.scad, sm_key.scad, unified35.scad]
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2017-10-28 missed save
    [dim.scad]
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2017-10-30 gecko and shock fixes
    [unified.scad]
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2017-11-03 fixes to code for shock2
    [dim.scad, unified.scad]
2017-11-05 clean up bugs from the refactor
    [saber.ino]
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2017-11-06 zone2 fixes. add resistor pcb
    [unified.scad]
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2017-11-29 fix up id string
    [pins.h]
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2017-12-28 work on the unified tali. 2 possible designs for upper pcb
    [beam.scad, unified.scad]
2017-12-29 teaks to design. still concerned about the forward battery holder
    [buttress.scad, unified.scad]
2018-01-09 clean up button. add pendant. (this version won't print)
    [pendant.scad]
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2018-01-23 add the ahsoka parts. software for ahsoka sabers
    [standard.scad]
2018-01-24 next version of ahsoka hilt. reworked shapes utilities
    [shapes.scad, standard.scad]
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2018-02-15 fixes after print
    [dim.scad, unified.scad]
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2018-03-01 big changes to testing code. pull out dead code. switch to new interface
    [dim.scad, unified.scad]
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2018-03-07 fix bugs and output of test cases
    [commonUnified.scad, unified.scad]
2018-03-10 fix the cover logic. simplify cover.
    [unified.scad]
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2018-03-10 missing experimental files
    [heatsink.scad, lift.scad]
2018-03-10 design fixes
    [commonUnified.scad, unified.scad]
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2018-03-21 dotstar support, first pass at tali crystal coupler
    [commonUnified.scad, unified2.scad]
2018-03-23 testing fixes and fixes and fixes
    [unified.scad]
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2018-04-09 clean up tali files. first cut at spacers.
    [beam.scad, buttress.scad, spacers.scad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]
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2018-05-09 fix some constants.
    [unified2.scad]
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2018-05-27 add overrides for UI sounds. fix efficiency in LED calc
    [unified.scad]
2018-05-28 fixes for tali (vigilance)
    [pins.h, saber.ino]
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2018-06-01 prophecy and stunt1 tweaks. improvements to common part
    [commonTest.scad, commonUnified.scad, unified.scad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]
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2018-06-24 adding cqueue infrastructure. fixes for new TANO tests.
    [pins.h]
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2018-06-24 fix the port center
    [dim.scad]
2018-06-30 rewrite audio2. fix pins.
    [pins.h]
2018-06-30 remove (this version) audio2. tweak dims for prophecy
    [dim.scad]
2018-07-05 add basic land patterns to pcb. tweak the sisters parts
    [commonUnified.scad, dim.scad, unified2.scad]
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2018-07-18 fix pins for v5
    [pins.h]
2018-07-19 try to fix ui volume bug
    [pins.h]
2018-07-21 itsy pcb iteration. initial sketch of dotmatrix being driven by shift reg.
    [unified2.scad]
2018-07-21 fix itsy power supply wiring
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2018-08-04 support for dotstar ui rendering. fix a minor dotstar assert error.
    [pins.h]
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2018-08-19 fixes for the new sisters ui.
    [pins.h, saber.ino]
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2018-08-23 remove dead code. fix sister resistor values. try to better initialize display
    [DotStar.cpp, pins.h, saber.ino]
2018-08-24 fix the sisters forward part
    [commonUnified.scad, unified2.scad]
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2018-08-31 break out front LED holder as a reusable part
    [commonTest.scad, commonUnified.scad, unified2.scad]
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2018-09-14 Accel test tweak. New much better random number generator.
    [dim.scad]
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2018-09-27 Fix the ui sound bug at startup. Add unified carriage for kenobi.
    [commonUnified.scad, dim.scad, unified.scad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]
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2018-10-01 trying to work out the very small plate...
    [unified.scad]
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2018-10-09 evolve the parts. short version of stunt saber.
    [commonUnified.scad, dim.scad, holder.scad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]
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2018-10-26 sync back from 'saber' source. initial locks to try to fix lockup/crash
    [pins.h, saber.ino]
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2018-10-27 working through issues in board
    [pins.h, saber.ino]
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2018-10-30 fixing asserts and blade logic
    [pins.h]
2018-10-31 refactoring for RGB to namespace. neopixel support. bug fixes
    [DotStar.cpp, pins.h, saber.ino]
2018-10-31 bug fixin and ui tweaks
    [pins.h]
2018-10-31 track some bugs. initial itsy v1b layout.
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2018-12-15 tune down audio buffer size. fix template printing.
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2018-12-21 bug fixes on aquatic-2. getting code up to speed again
    [pins.h, saber.ino]
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2019-01-04 coupler fixes
2019-01-04 changes and fixes for aquatic-2
    [unified.scad]
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2019-01-17 Rework of the LED system. Fixed point math to compute more accurate colors. fixed point sin. Use hardware brightness for dotstar
    [DotStar.cpp, pins.h, saber.ino]
2019-01-18 rework how brightness is managed in code. saber.ino now uses RGBA
    [pins.h, saber.ino]
2019-01-19 bug fix in blade flash. fixed point errors and improvement. improved debugging. start testing.
    [pins.h, saber.ino]
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2019-02-16 pcb4 redesign
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2019-02-25 missing file
    [inset.scad]
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2019-03-06 fixes doing cut
2019-03-07 tweaks. bug notes
    [commonUnified.scad, inset.scad, unified.scad]
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2019-03-09 simplify accel to speed. first testing tyvokka board
    [unified.scad]
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2019-03-12 add missing baffles
    [baffles.scad]
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2019-03-30 fix voltmeter startup
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2019-04-10 bug fixing voltmeter code
2019-04-10 partial merge from looping-audio. bug fixes. testing.
    [saber.ino]
2019-04-15 fix nut holder
    [inset.scad]
2019-04-21 fix motion / impact, working on accel
    [saber.ino]
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2019-05-09 fixes, tweaks, and merging.
    [pins.h, saber.ino]
2019-05-09 fixes and deployed to tyvokka
    [pins.h]
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2019-07-08 general improvement to baffles and unified carriage. initial graflex
    [commonUnified.scad, dim.scad, unified.scad]
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2019-08-05 parts to improve the graflex. another take at a heatsink to wiring coupler
    [coupler.scad, heatSleave.scad]
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2019-08-28 improved lsm303. fixed point sqrt
    [lsm303.ino]
2019-08-28 fixes and clean up api. rate control for magnemometer
    [lsm303.ino]
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2019-09-13 oled work, revan improvements, lots of work on unified
    [commonUnified.scad, dim.scad, inset.scad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]
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2019-09-14 missing graflex parts
    [graflexButton.scad, graflexButtonB.scad]
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2019-09-22 fixing lsm303. optimize monochromatic oled rendering
    [lsm303.ino, oled.ino]
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2019-10-21 lots of work on i2s. so broken, jettising v1 and writing v2
    [flashmemwriter.ino, i2saudio2.ino, lsm303.ino]
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2019-11-09 shock 3 cutting path. missing files from saber refactor
    [unified.scad]
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2019-11-21 fix switchplate offset
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2019-12-04 reinforce back of shock carriage
    [commonUnified.scad, unified.scad]
2019-12-08 collected fixes, basic testing on the itsy
    [saber.ino]
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2019-12-09 fixes for shock3
    [commonUnified.scad, dim.scad, unified.scad]
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2020-01-17 fix multi-instanced voltmeter
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2020-01-25 rework the scaffold. try a different experiment with leia part. enter in bench test for v2c
    [commonUnified.scad, scaffold.scad, unifiedA.scad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]
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2020-02-08 test and fix color
    [saber.ino]
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2020-02-10 fix many many bugs in the saber code
    [pins.h, saber.ino]
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2020-02-12 fix in testing
    [switchholder.scad]
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2020-02-17 fixes for release of leia
    [unifiedB.scad]
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2020-02-23 fix color wheel
2020-02-24 working on smooth swing. kind of working-ish delta bunches of bugs.
    [saber.ino]
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2020-03-06 fix the dotstar code
    [DotStar.cpp]
2020-03-10 fixes to sound system
    [pins.h]
2020-03-11 fixes for getting leia saber working
    [pins.h, saber.ino]
2020-03-16 lots of fixes for 1.0 of leia
    [killkeyholder.scad, unifiedA.scad]
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2020-03-28 working on sisters2 parts. add a bolt holder
    [commonUnified.scad, dim.scad, inset.scad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]
2020-03-30 improve the common and sister2 parts. experimental joint. improved bolt holder.
    [commonUnified.scad, unified.scad]
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2020-04-07 fixing bugs. getting oled test working. setting up sisters2
    [oled.ino, saber.ino]
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2020-04-18 work on ilum, sisters2, and improved vector UI
    [commonUnified.scad, dim.scad, unified.scad]
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2020-04-23 formatting fixes
    [unified.scad]
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2020-05-14 fix the display loop, fix formatting
    [saber.ino]
2020-05-14 bug fixes for ilum
    [commonUnified.scad, unified.scad]
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2020-05-18 redesign ilum saber to use power coupler
    [dim.scad, dimCoupler.scad, powerCoupler.scad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]
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2020-05-20 part fixes
    [dimCoupler.scad, ventcap.scad]
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2020-05-22 fixing parts
    [dim.scad, dimCoupler.scad, powerCoupler.scad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]
2020-05-23 another round of parts fixes
    [flipjig.scad, unified.scad, ventcap.scad]
2020-05-23 fixes printing
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2020-06-01 code to get dutchess/ilum running, including rotated front and mag filtering
    [unified.scad]
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2020-06-06 fixes for ilum release. change sound font
    [pins.h]
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2020-06-18 fix the oled rendering
    [saber.ino]
2020-06-19 fix error and sin
    [i2saudio2.ino, pins.h]
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2020-07-18 audio fixes, parts, working on sisters2 release
    [unified.scad]
2020-07-28 get the staff working (whew). Update the other mag-based sabers
    [commonUnified.scad, unified.scad]
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2020-09-05 fix, hopefully, the copper cut
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2020-09-18 final shop fixes
    [unified2.scad]
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2021-03-01 trying to fix button alignment
2021-03-08 fixing up black saber
    [pins.h]
2021-03-08 rework clan sabers
    [commonUnified.scad, switch.scad, unified.scad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]
2021-03-13 lots of clan fixes
    [commonUnified.scad, dim_apprenticeV4.scad, dim_prophecy.scad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]
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2021-04-10 fix print bug
    [unified.scad]
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2021-06-12 fixes from printing clan
    [commonUnified.scad, dim.scad, dim_aeonv4.scad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]
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2021-07-17 shop fixes
    [dim_apprenticeV4_LE.scad, dim_prophecy.scad, unified.scad]
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2021-07-17 updating and working on audio bug
    [pins.h, saber.ino]
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2021-08-12 testing and fixing PCBs
    [pins.h, saber.ino]
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2021-08-29 reworking the leia design
    [baffles.scad, commonUnified.scad, dim.scad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]
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2021-11-27 big refactor of accel, fixed math
    [pins.h, saber.ino]
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2022-02-02 fixing up serial output
    [pins.h]
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2022-03-03 accumulated fixes working on prophecy locks and upgrade
    [pcbAligner.scad]
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2022-04-23 tweaks. fixing mechanical bugs
    [dim.scad, unified.scad]
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2022-05-14 fix tube offset
    [dim.scad, unified.scad]
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2022-05-28 fixing fixed point issues
    [pins.h, saber.ino]
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2022-06-07 fix compilation on arduino
    [saber.ino]
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2022-06-24 compile fixes
    [pcbAligner.scad]
2022-06-25 fixes, testing, switch work
    [switch.scad]
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2022-08-06 testing and fixing new saber code
    [i2saudio2.ino, lsm6d.ino, pins.h]
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2022-10-10 fixes. tests. alternate timing.
    [pins.h, saber.ino]
2022-10-13 wip fixing lots of things, but primarily turbopwm
    [pins.h, saber.ino]
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2022-10-14 bug fixing. color correction.
    [saber.ino]
2022-10-15 bug fixing getting the darksaber running again
    [i2saudio2.ino]
2022-10-22 bug fixes, audio improvements for darksaber
    [killkey.scad]
2022-12-07 wip on fixing lsm303
    [lsm303.ino, pins.h, saber.ino]
2022-12-10 working on fixing swing
    [lsm303.ino, pins.h, saber.ino]
2022-12-10 swing really not working well. sync to revert back
    [pins.h]
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2023-03-05 tweaks and setting up for the new printer
    [commonUnified.scad, dim.scad, unified.scad]
2023-03-05 rework the red LED math
    [pins.h]
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2024-01-15 minor chamber fixes
    [chamber.scad]
2024-01-16 fixes to chamber
